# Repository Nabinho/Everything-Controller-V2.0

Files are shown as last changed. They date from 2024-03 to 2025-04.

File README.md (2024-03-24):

# Everything Controller V2.0

This project is an updated version of my Everything Controller I did a while back. This time I focused on transmission time, using the powerfull Teensy 3.2 as the main microcontroller. I also added more inputs, so I have even more functions to help the control of various projects, and not only robots.

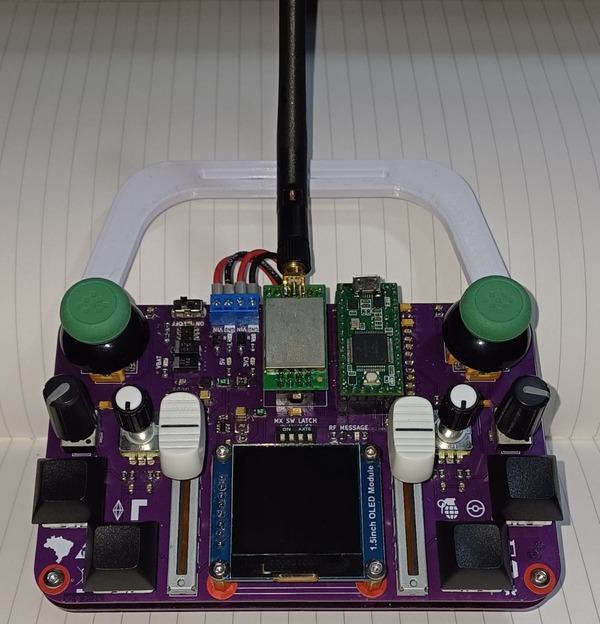
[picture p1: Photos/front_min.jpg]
Finished project


The PCB and base code of this project are available for replication. The Teensy 3.2 is discontinued, so if you don't have one, maybe this can be a great reference for your own project.

## BOM

The SMD components list can be found in the interactive BOM generated with the KiCad project. Besides the Teensy 3.2 I had for a while, the rest of the THT components I bought from Aliexpress and all of the links are listed below.

* 1x - [EByte E01](https://pt.aliexpress.com/item/1005001803228202.html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);
* 1x - [Waveshare SSD1327 128x128 OLED Display](https://pt.aliexpress.com/item/32853228170.html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);
* 2x - [10k Ohm Rotary Potentiometer](https://pt.aliexpress.com/item/1005005956593595.html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);
* 2x - [10k Ohm Slider Potentiometer](https://pt.aliexpress.com/item/1005006075347058.html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);
* 2x - [EC11 Rotary Encoder](https://pt.aliexpress.com/item/1005005882895811.html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);
* 4x - [Cherry MX Switches (any color)](https://pt.aliexpress.com/item/1005006255961111.html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);
* 2x - [PS5 Hall Effect Joystick](https://pt.aliexpress.com/item/1005006165745072.html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);

Besides the electronics components, a pair of 18650 Li-Ion batteries is necessary to power the controller.

Some screws and nuts ares also recommended to mount the soldered PCB in an acrylic or 3D printed backplate.

## Bechmark Tests

As soon as the controller was finished I ran some benchmark tests to validate the controller performance. Bellow are the tests I ran so far and the results.

| Tests | Results |
| --- |:---:|
| Battery feedback reading | The battery feedback circuit from the controller had a precision of 0.3 mV most of the time, but I had to include a "debounce" for the OLED update, due to some voltage fluctuation |
| Transmission latency | With a simple receiver just connected to the NRF24L01 transceiver and only calculating the time between messages (data sent and acknolegement) the average time was 3 ms during an 1 hour test |
| Battery duration | Using a pair of 3000 mAh 18650 Li-Ion batteries the controller stayed turned on during 21 hours (average consumption of 150 mA) |
| Transmission range | This test is still TBD, however I want to see if the optimistic expectations from EByte of a transmission range of 5 km is true |

### Conclusion/Contact

As this is a personal project, I would love to see if anyone replicate or takes inspiration from this project. So if you replicate or use this as a base for your own project, please share it with me in Instagram.

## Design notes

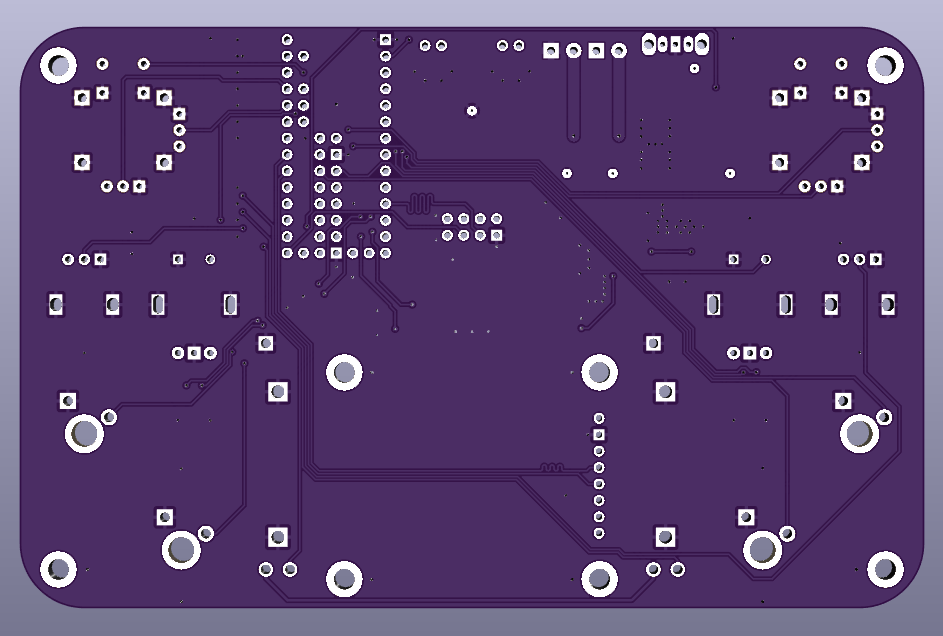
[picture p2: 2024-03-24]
Hardware/Everything_Controller_V2.0/photos/pcb_back.png

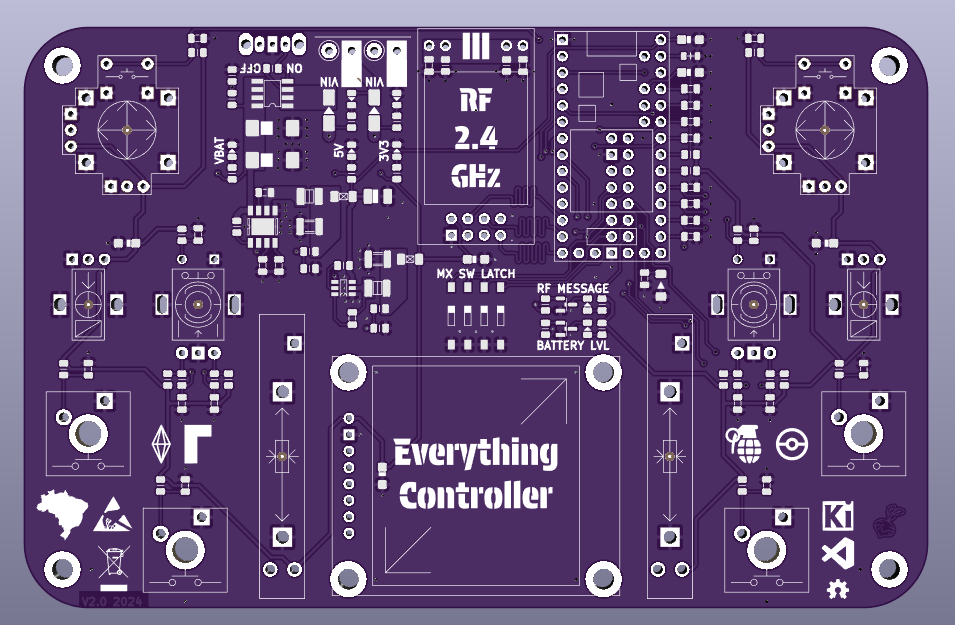
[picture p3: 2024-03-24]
Hardware/Everything_Controller_V2.0/photos/pcb_front.png

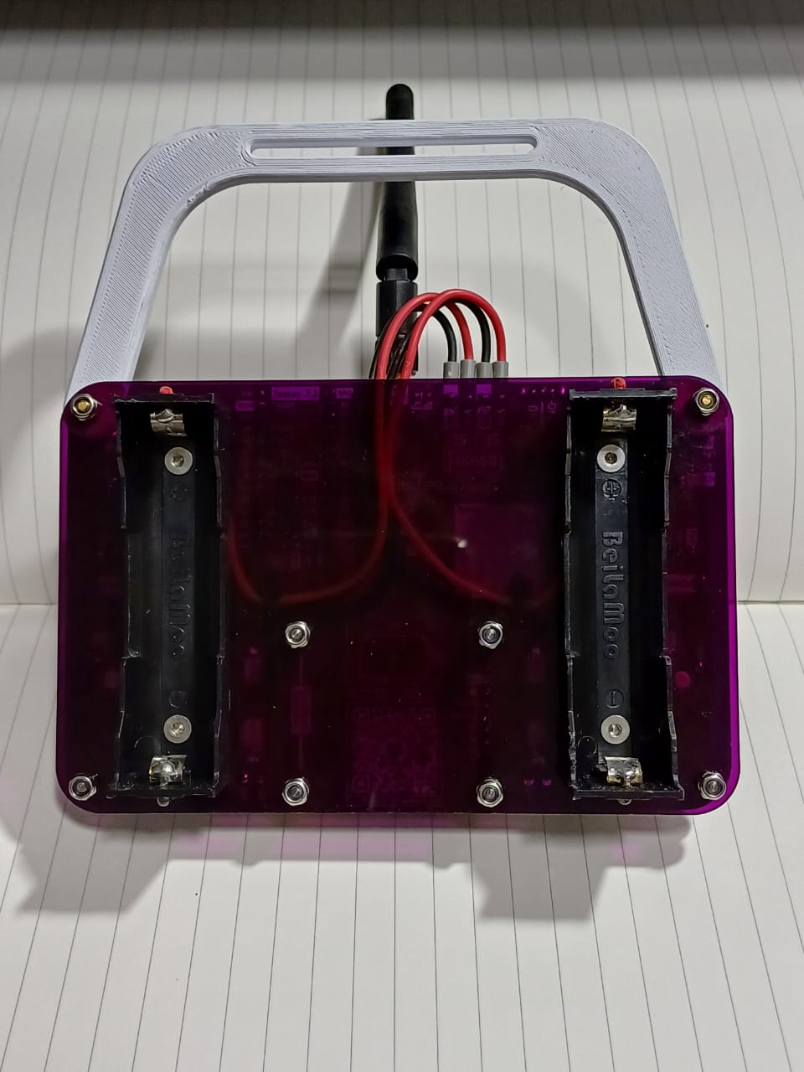
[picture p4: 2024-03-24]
Photos/back.jpg

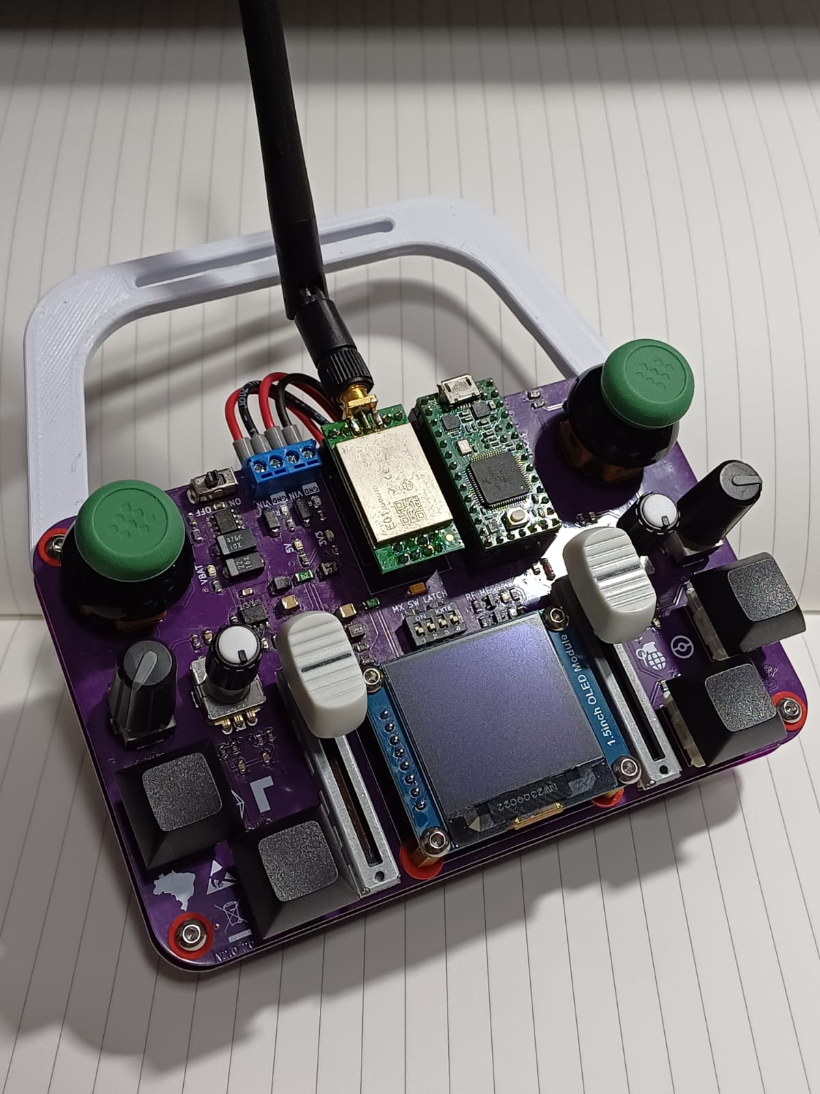
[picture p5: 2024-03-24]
Photos/isometric.jpg

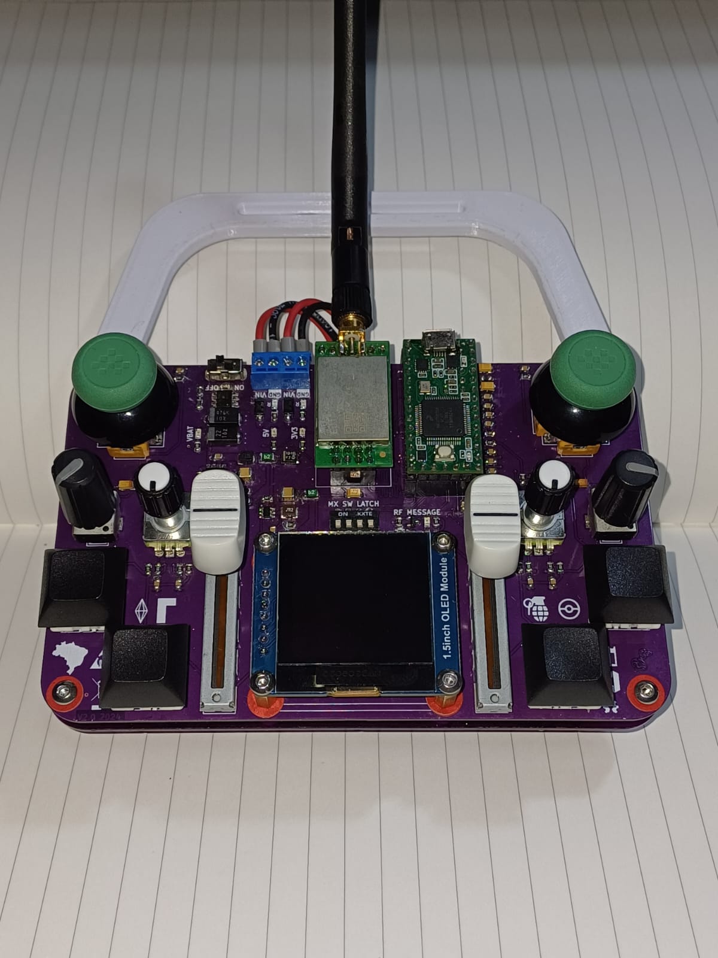
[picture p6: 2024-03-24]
Photos/front.jpg

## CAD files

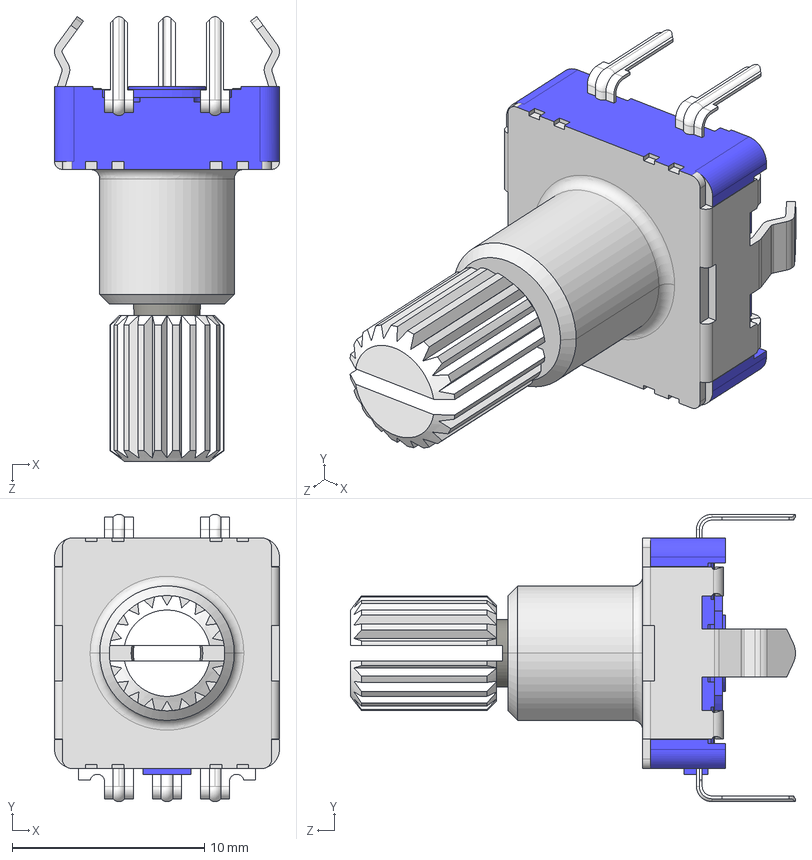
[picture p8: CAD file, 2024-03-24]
Hardware/Everything_Controller_V2.0/3d/EC11 Rotary Encoder Dode Switch-15mm .STEP
11.7 x 15.0 x 23.2 mm

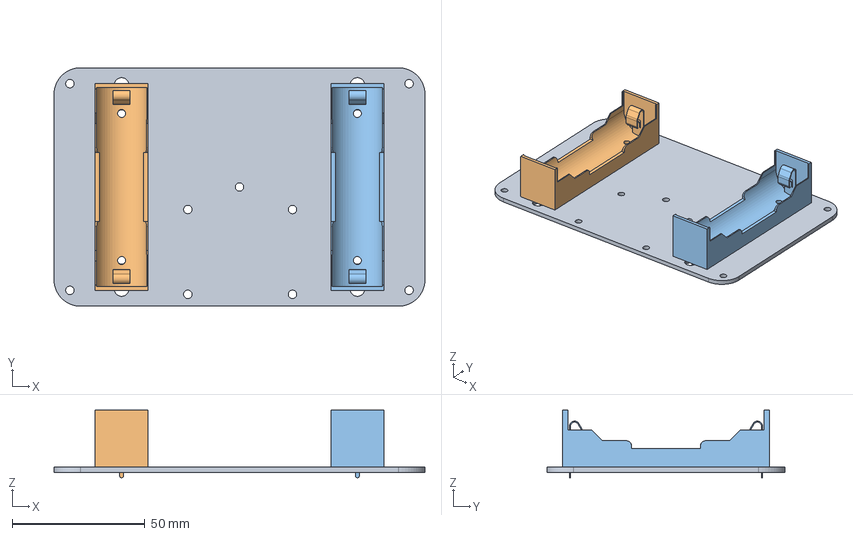
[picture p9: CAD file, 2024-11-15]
Hardware/Everything_Controller_V2.0/mechanical/Everything_Controller_Backplate.FCStd
140.0 x 90.0 x 25.5 mm
Hold_18650-1p
Hold_18650-1p001

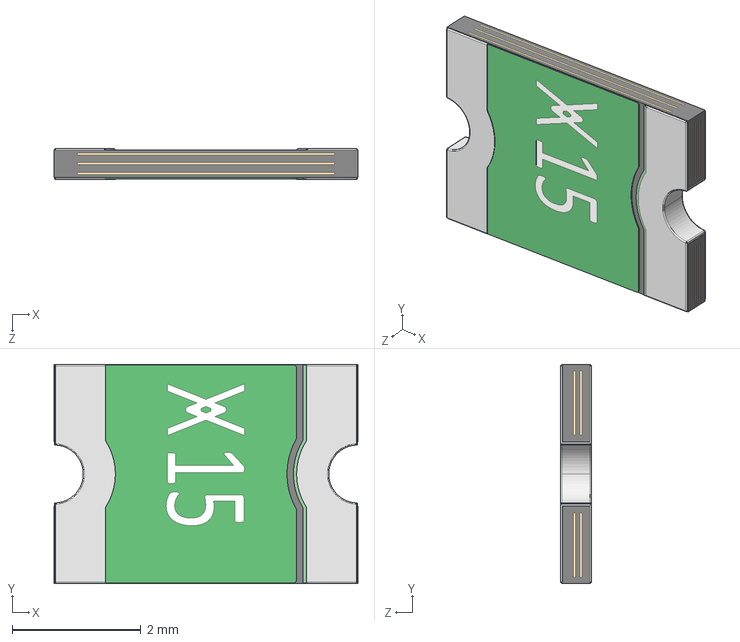
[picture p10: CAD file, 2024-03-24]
Hardware/Everything_Controller_V2.0/3d/miniSMDC150F.STEP
4.73 x 3.41 x 0.48 mm

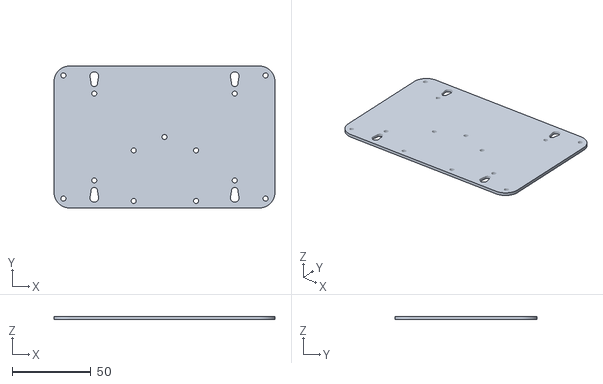
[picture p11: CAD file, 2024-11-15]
Hardware/Everything_Controller_V2.0/mechanical/Everything_Controller_Backplate-Body.stl
140.0 x 90.0 x 2.00

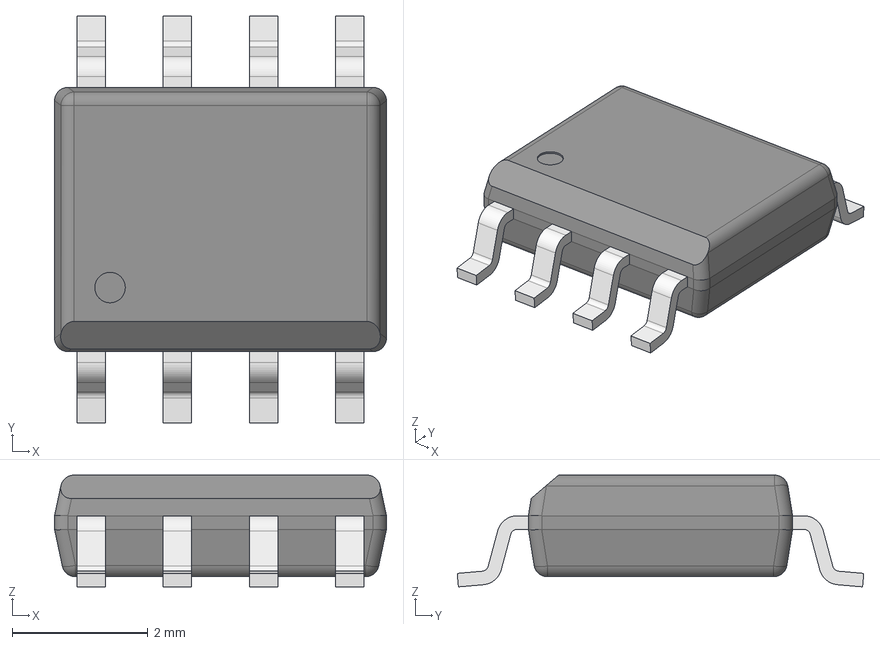
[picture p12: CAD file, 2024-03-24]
Hardware/Everything_Controller_V2.0/3d/Diodes_-_AP65552SP-13.step
4.90 x 6.00 x 1.65 mm

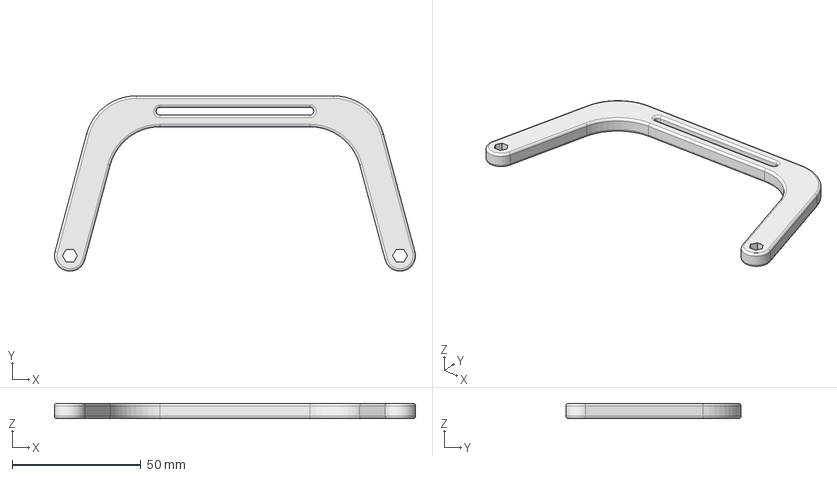
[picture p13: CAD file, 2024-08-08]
Hardware/Everything_Controller_V2.0/mechanical/Everything_Controller_Handle.FCStd
140.0 x 68.0 x 6.00 mm

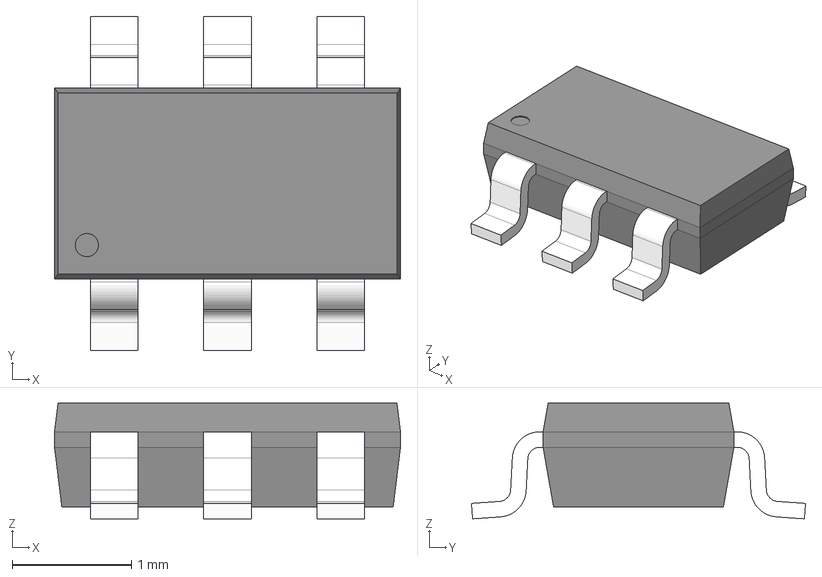
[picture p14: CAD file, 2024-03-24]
Hardware/Everything_Controller_V2.0/3d/Texas_Instruments_-_TPS564201DDCR.step
2.90 x 2.80 x 0.97 mm

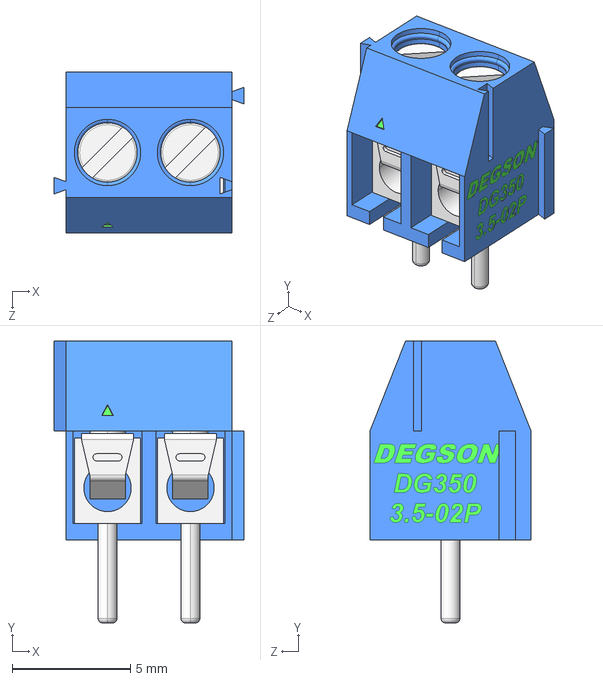
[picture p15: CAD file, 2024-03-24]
Hardware/Everything_Controller_V2.0/3d/DG350-3.5-02P-12-00AH.STEP
8.00 x 11.9 x 6.80 mm

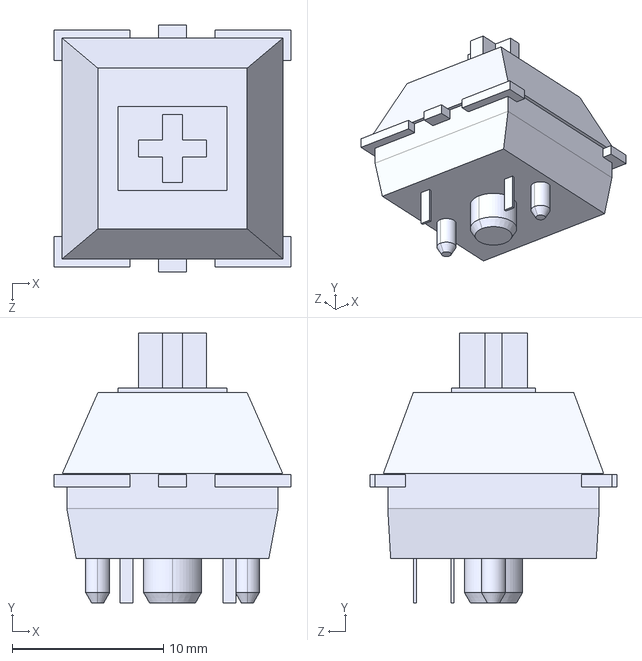
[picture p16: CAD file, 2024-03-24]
Hardware/Everything_Controller_V2.0/3d/cherry mx.STEP
15.6 x 17.9 x 16.3 mm

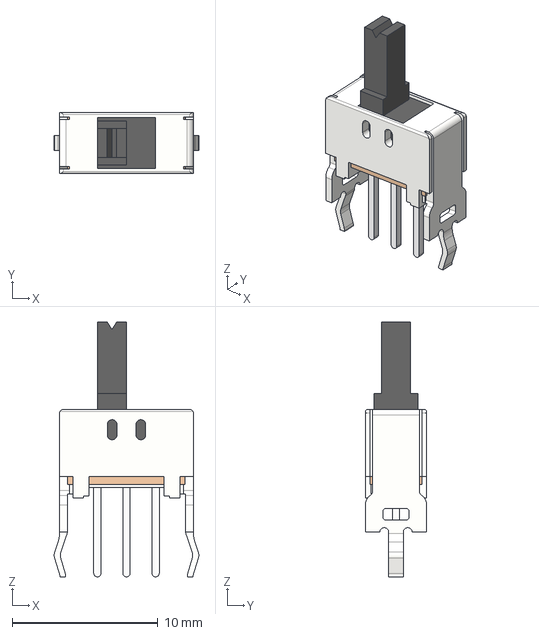
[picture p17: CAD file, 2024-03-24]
Hardware/Everything_Controller_V2.0/3d/EG1249.step
9.93 x 4.20 x 17.5 mm

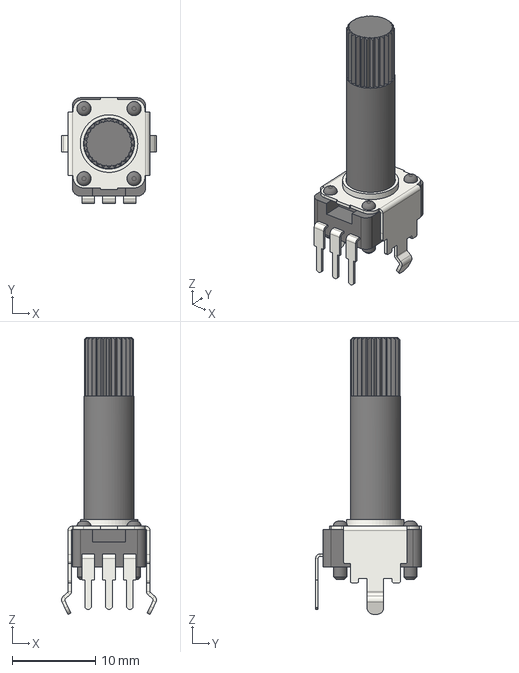
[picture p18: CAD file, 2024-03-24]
Hardware/Everything_Controller_V2.0/3d/ALPS-RK09K.step
11.4 x 12.7 x 33.2 mm

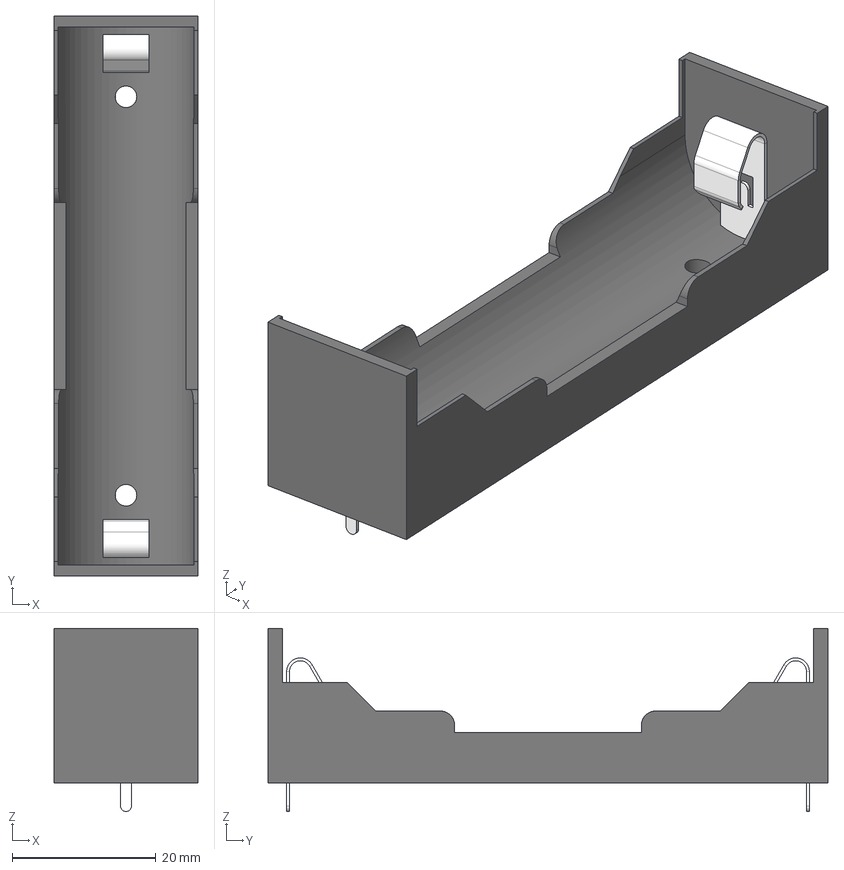
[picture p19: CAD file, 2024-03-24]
Hardware/Everything_Controller_V2.0/3d/Hold_18650-1p.stp
20.0 x 78.0 x 25.5 mm

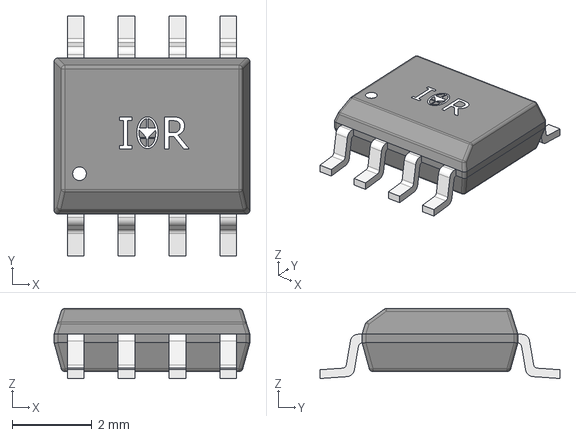
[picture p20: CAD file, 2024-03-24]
Hardware/Everything_Controller_V2.0/3d/Infineon_-_IRF7424TRPBF.step
4.90 x 6.00 x 1.75 mm

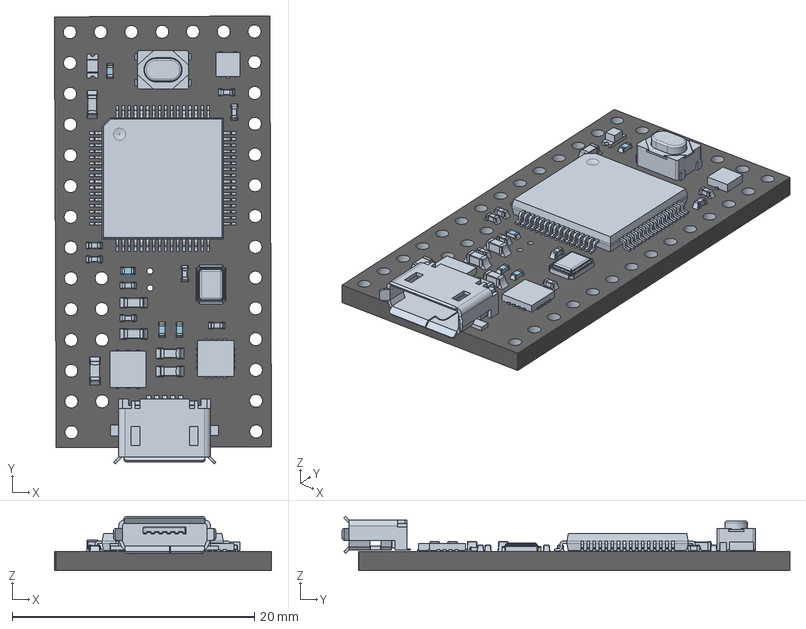
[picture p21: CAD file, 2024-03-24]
Hardware/Everything_Controller_V2.0/3d/Teensy_3_1.stp
17.9 x 37.0 x 4.49 mm
board
micro_usb_plastic (1)
micro_usb_shell (1)
lead
package (1)
lead (3) x 64
package
lead (1)
cap0402 v2 x 6
lead (2)
diode_0402 v1 x 4
cap0603_03 v3 x 5
cap0402 v2 (1) x 2
smt_led_0805 v2
resistor_0603 v3

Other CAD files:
Hardware/Everything_Controller_V2.0/3d/10K C3031 potentiometer.STEP
Hardware/Everything_Controller_V2.0/3d/SparkFun Deluxe Thumbstick with Breakout Board and Knob.step
Hardware/Everything_Controller_V2.0/mechanical/Everything_Controller_Backplate-Body.dxf

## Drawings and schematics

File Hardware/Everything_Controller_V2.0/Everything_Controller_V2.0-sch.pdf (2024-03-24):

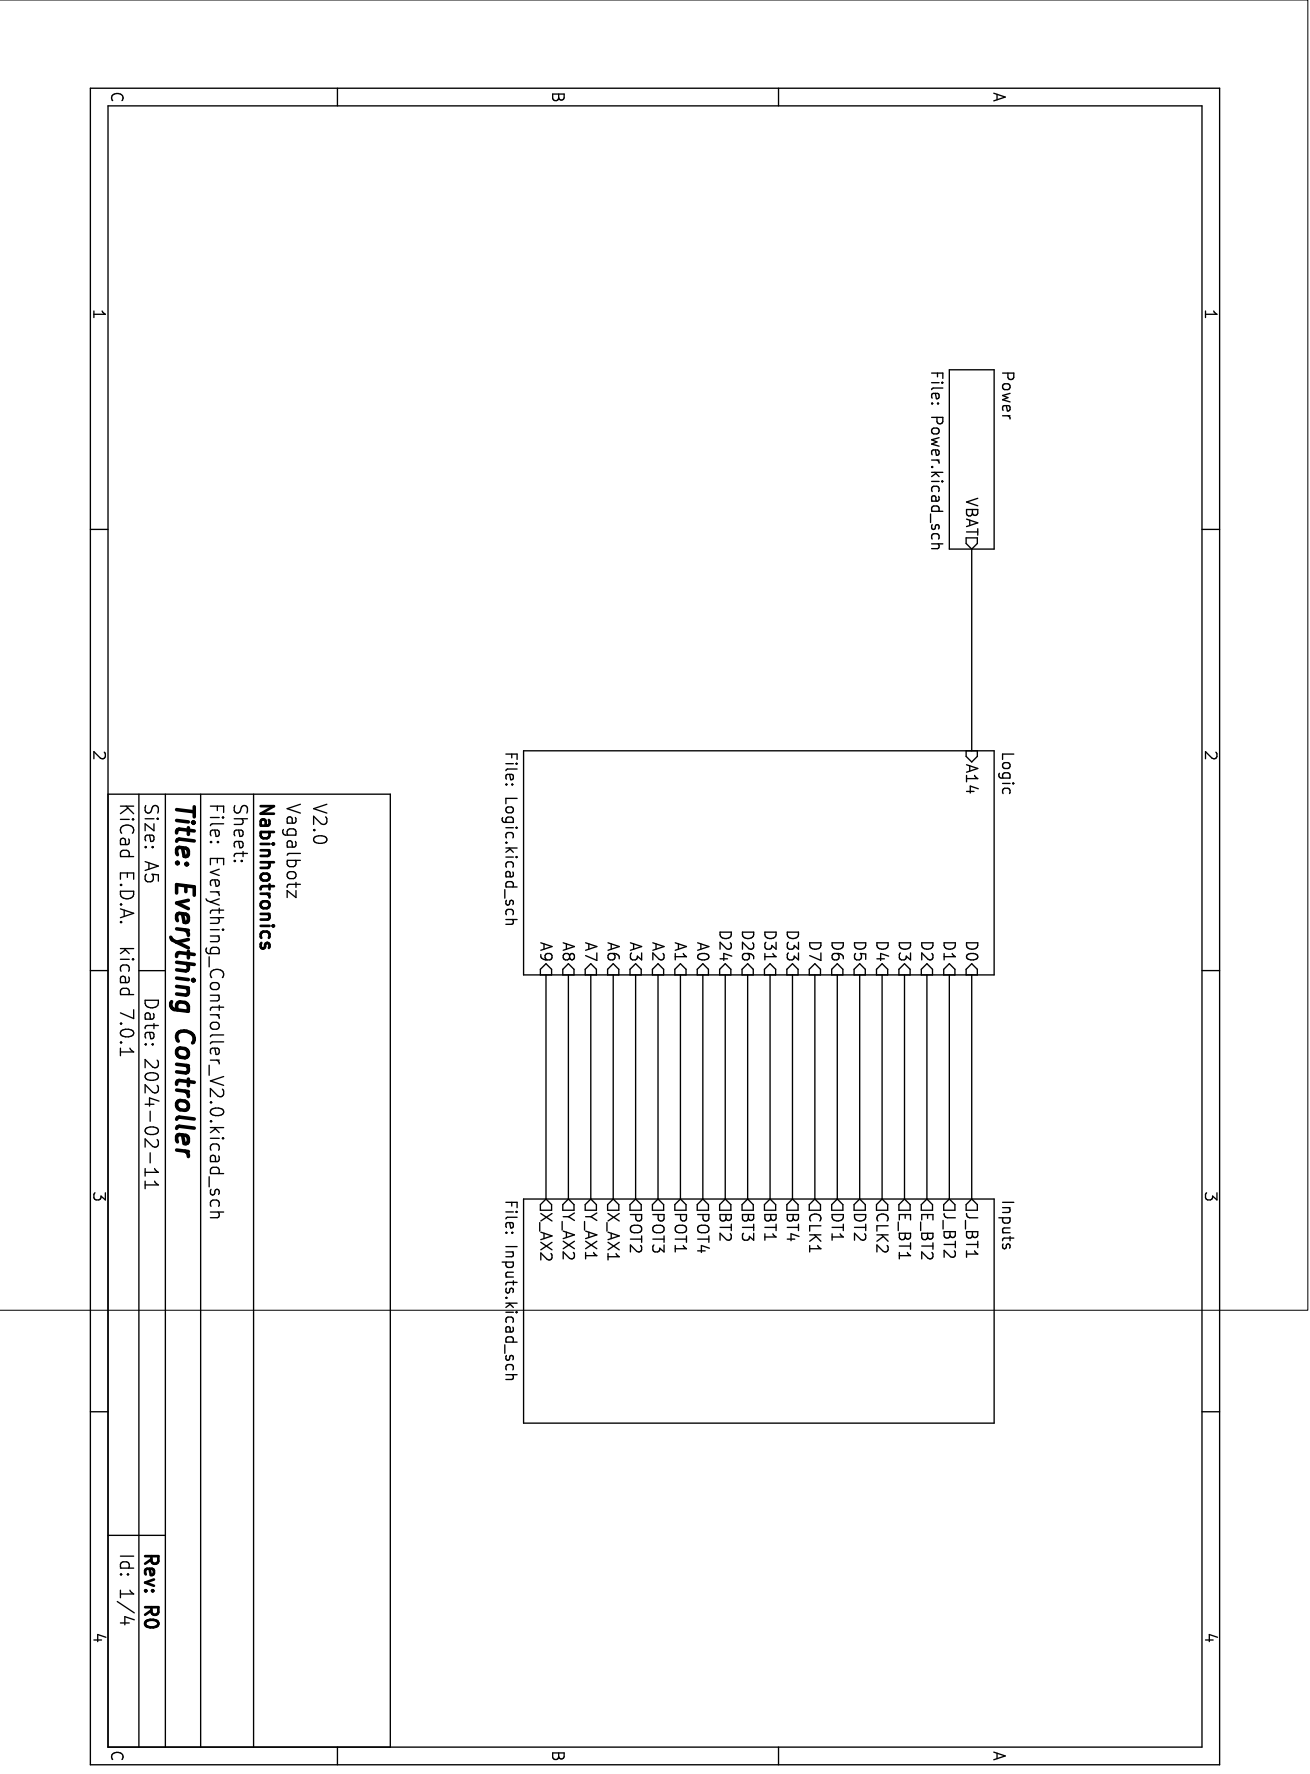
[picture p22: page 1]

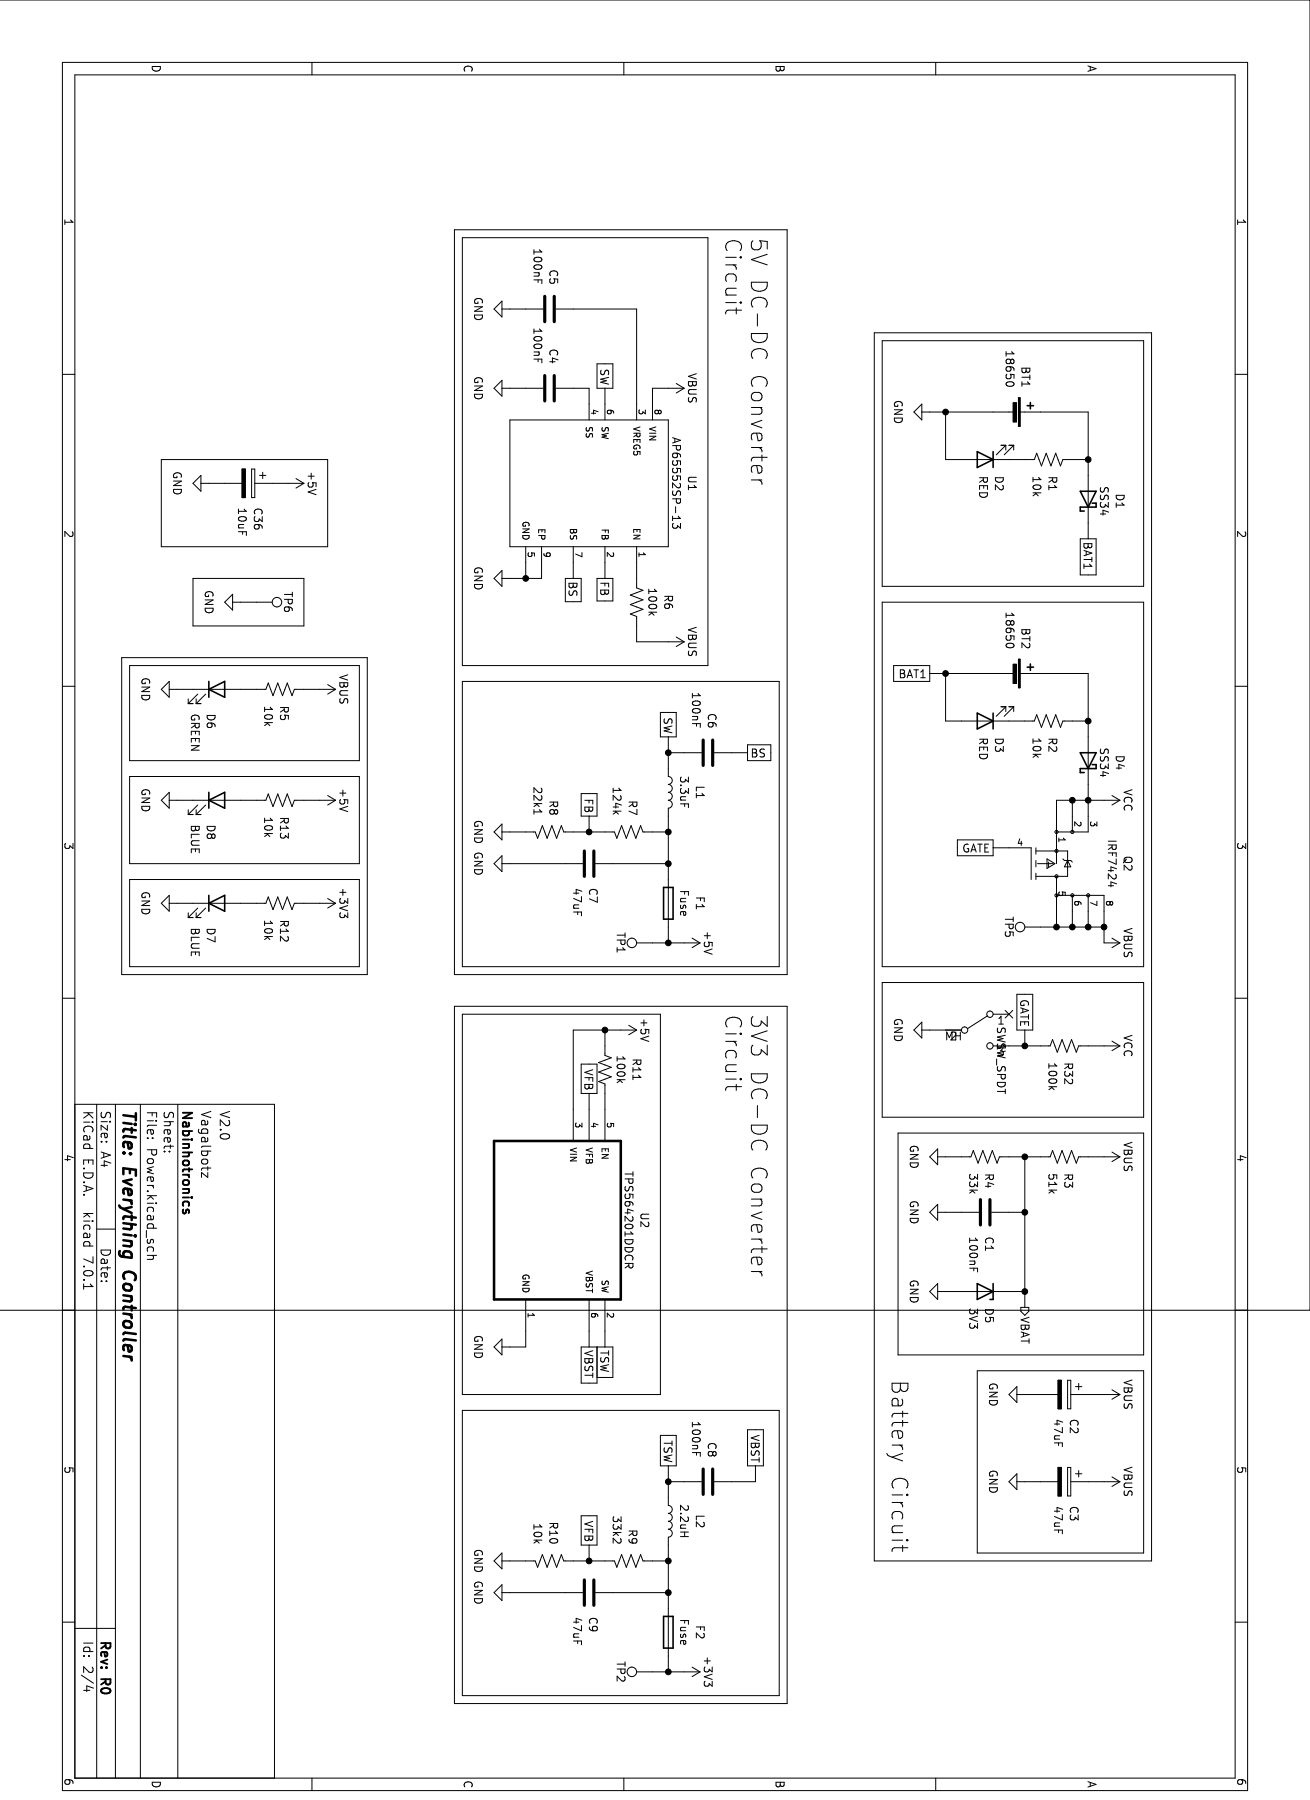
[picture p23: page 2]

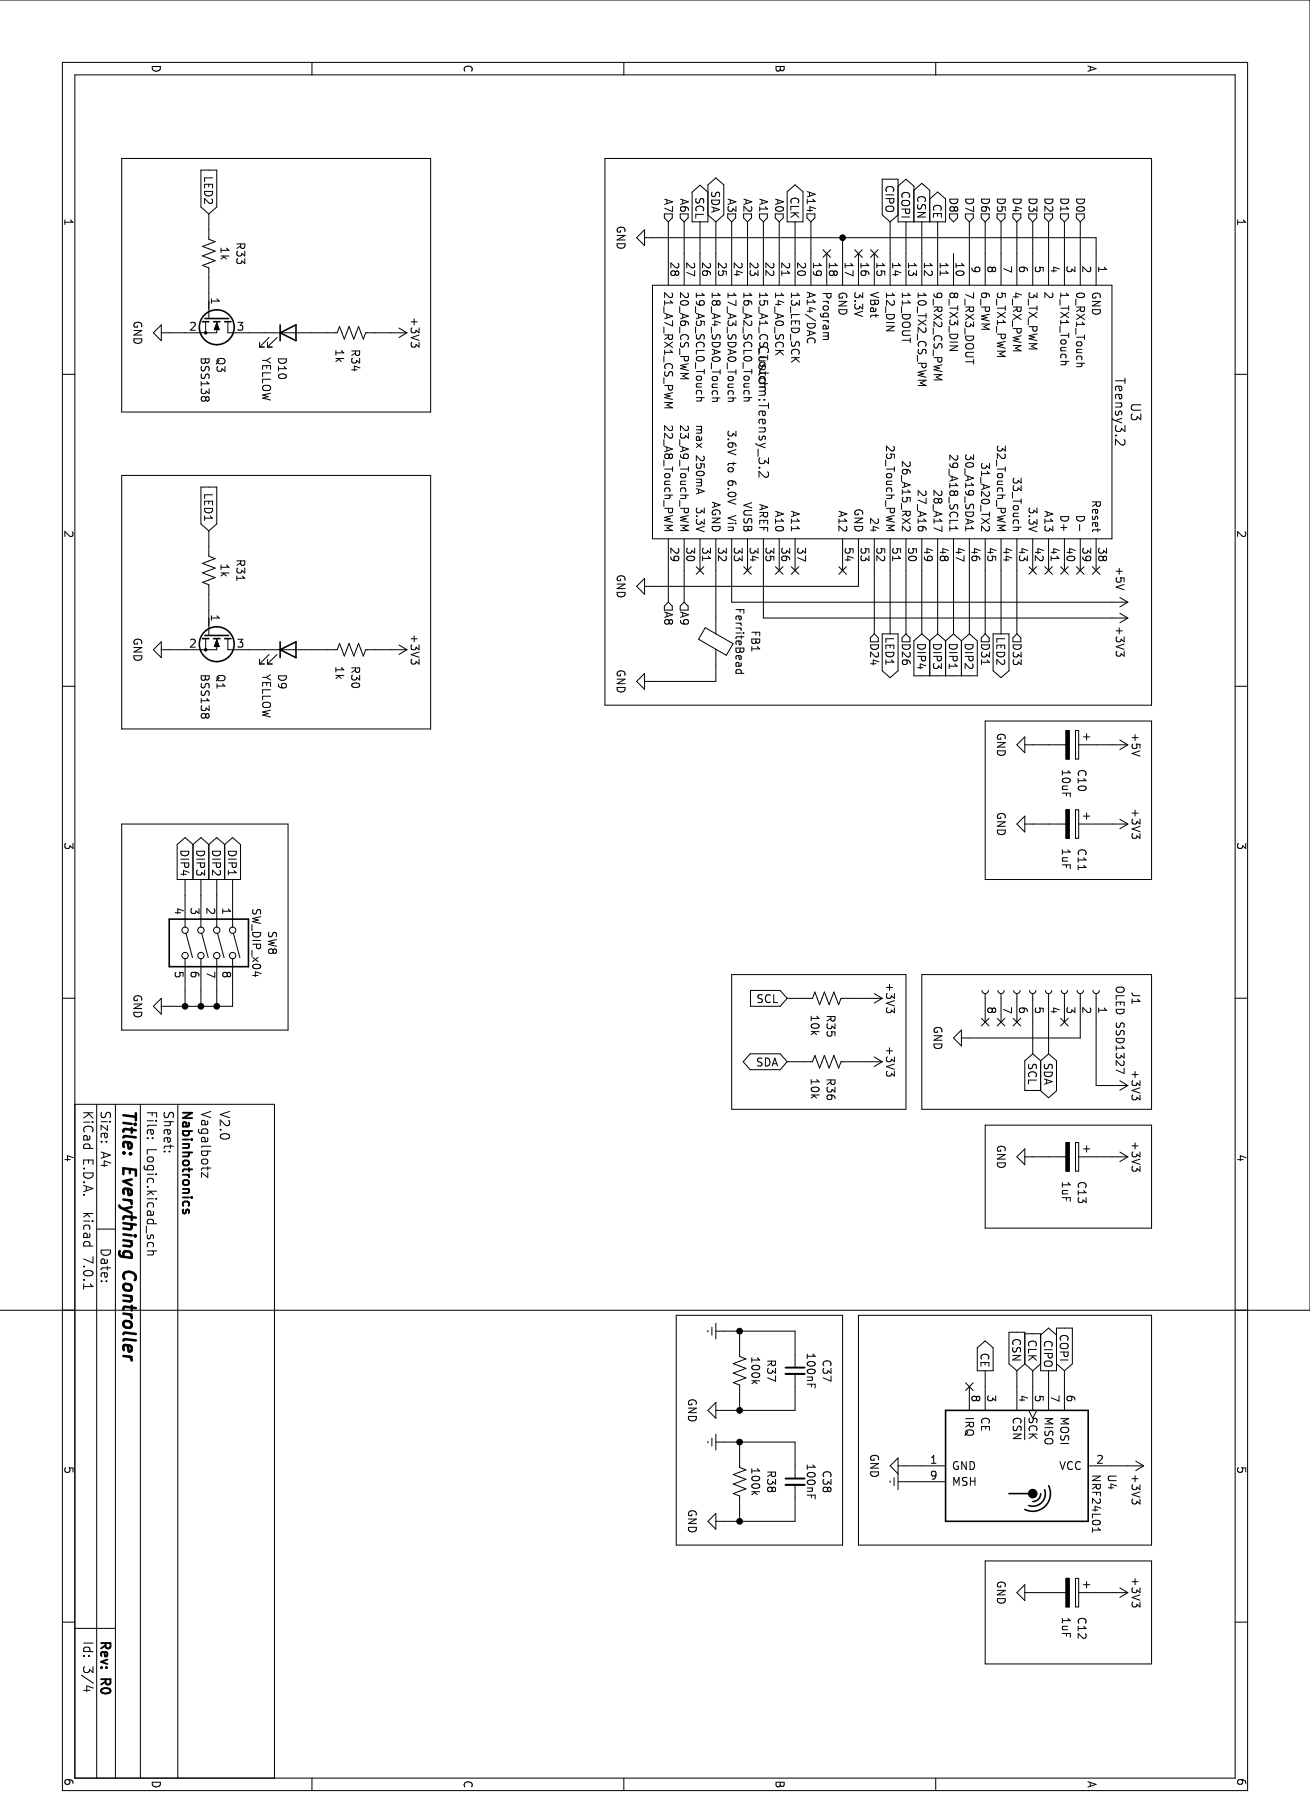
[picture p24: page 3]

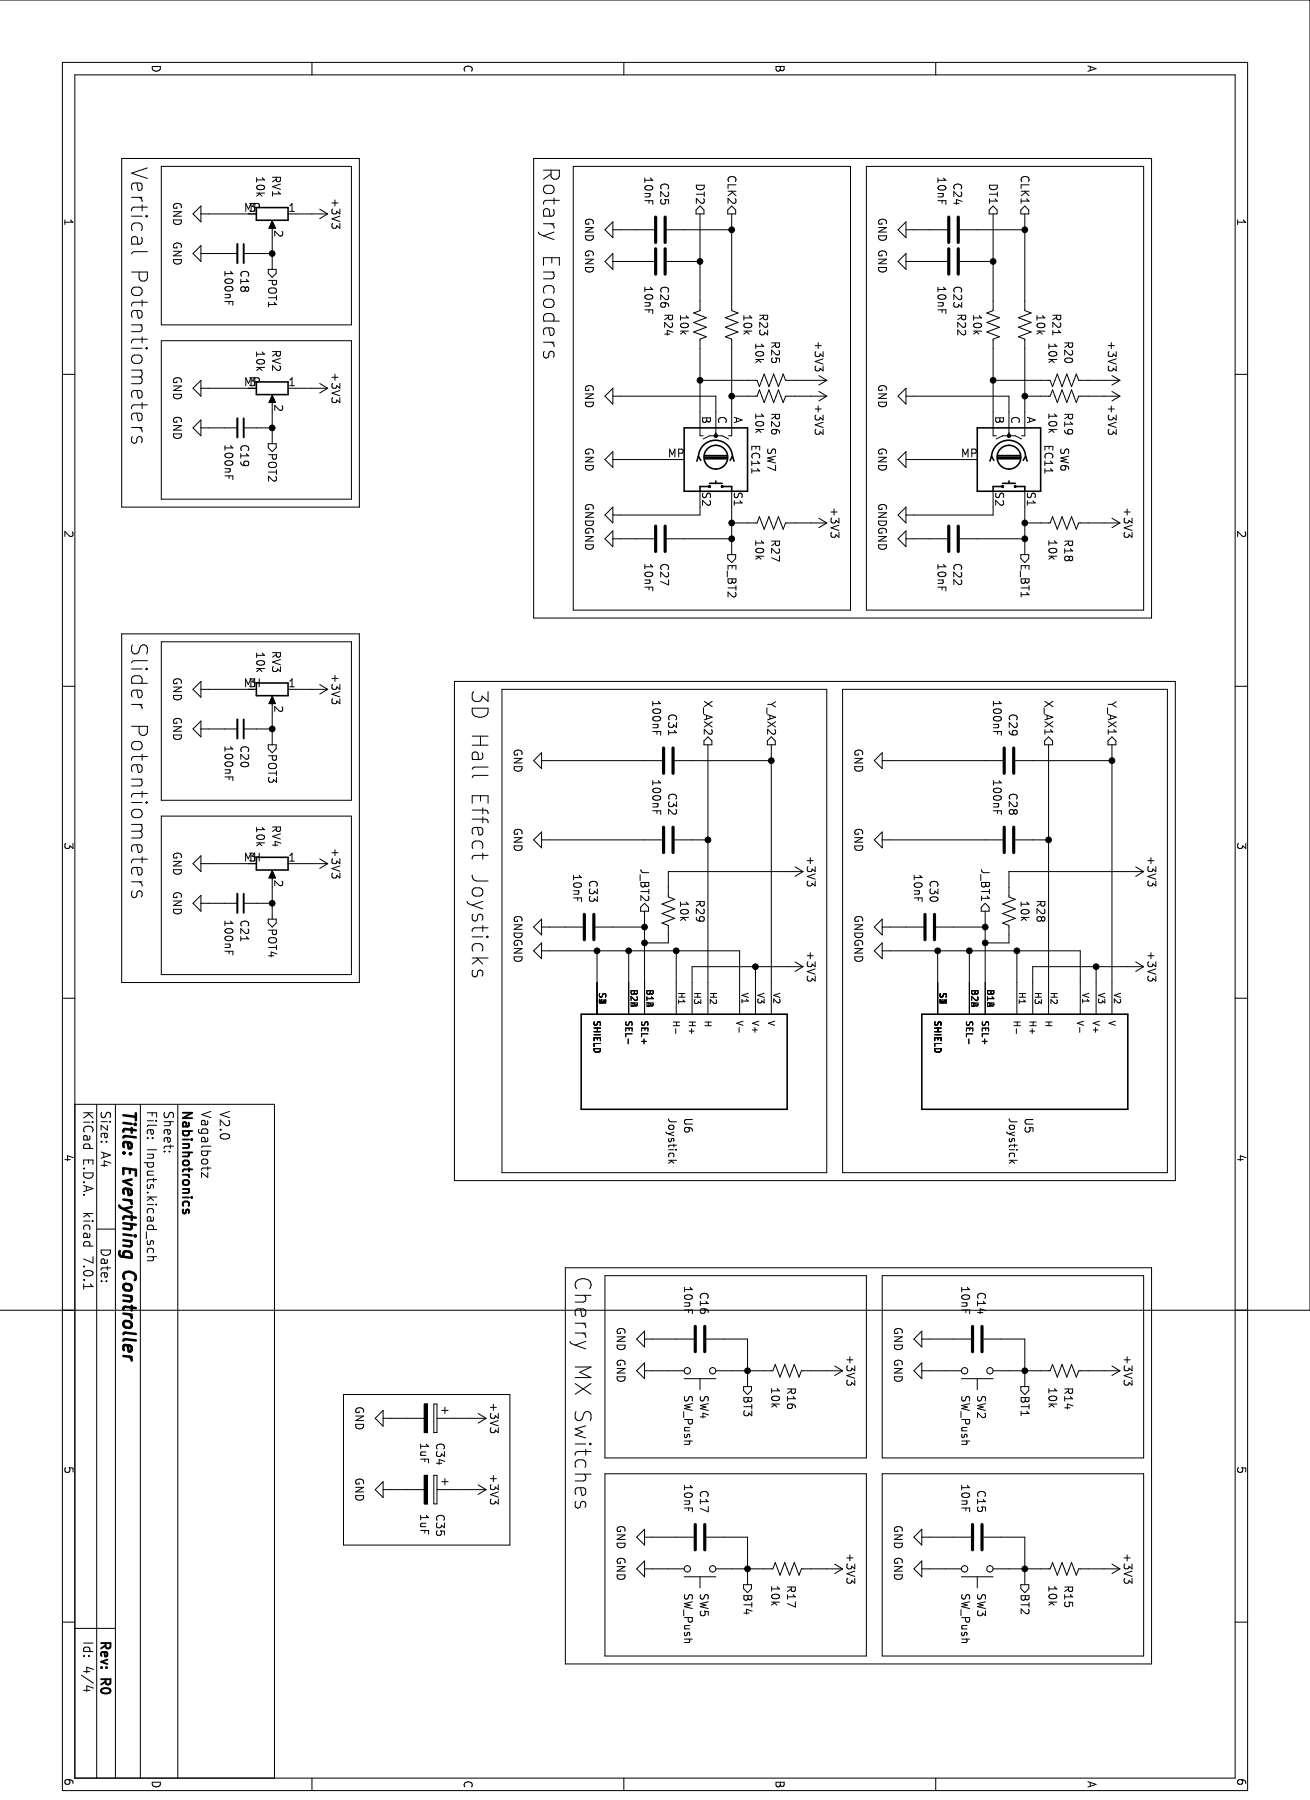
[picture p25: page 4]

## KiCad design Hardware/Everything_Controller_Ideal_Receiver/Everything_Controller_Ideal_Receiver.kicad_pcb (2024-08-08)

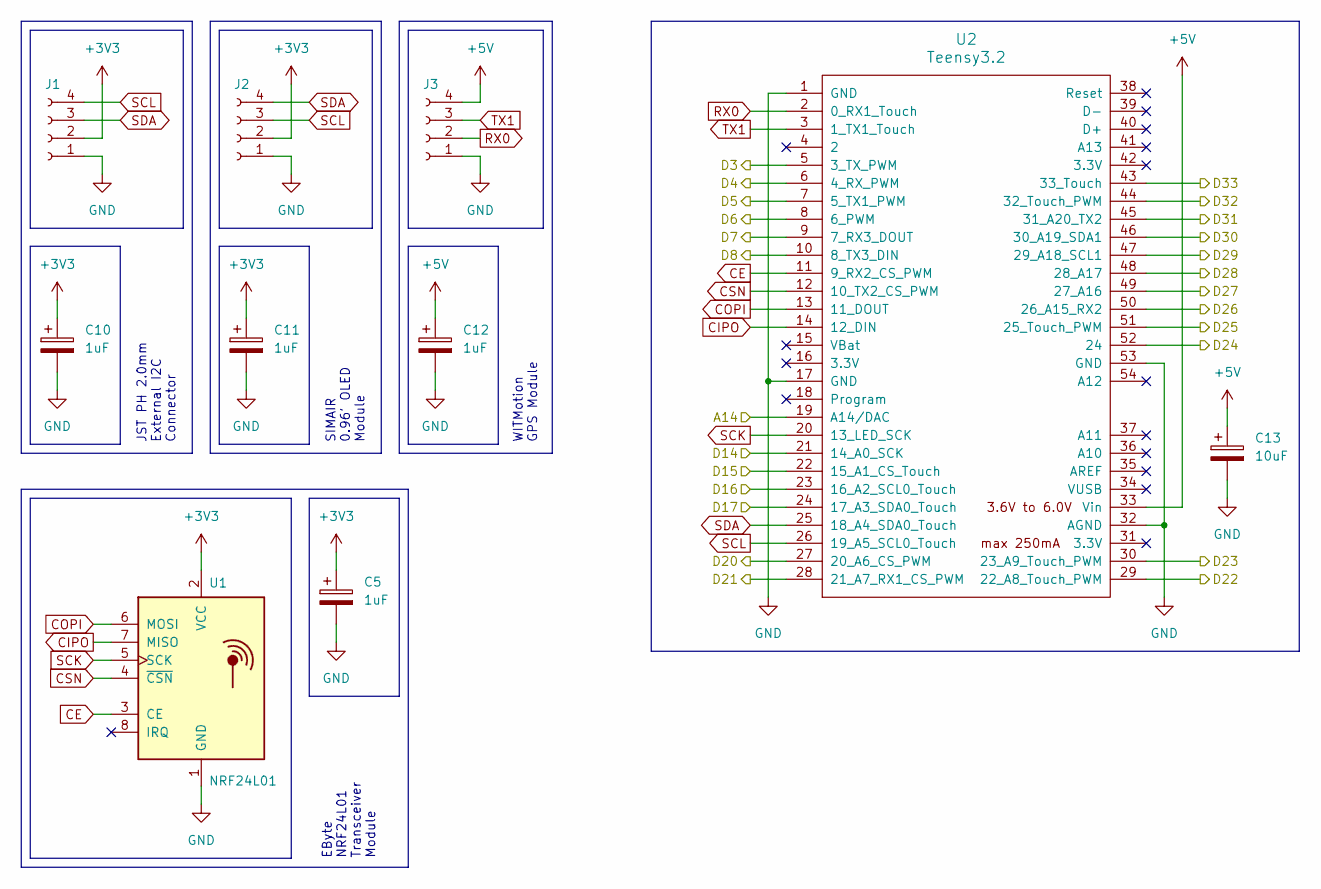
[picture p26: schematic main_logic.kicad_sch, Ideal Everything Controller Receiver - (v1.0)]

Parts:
C5, C10, C11, C12: 1uF; CP_EIA-3216-18_Kemet-A
C13: 10uF; CP_EIA-3528-21_Kemet-B
J1: Conn_01x04_Socket; JST_PH_S4B-PH-K_1x04_P2.00mm_Horizontal
J2: Conn_01x04_Socket; SIMAIR_OLED
J3: Conn_01x04_Socket; WitMotion_NMEA0183
U1: NRF24L01; EByte_NRF24L01_Breakout
U2: Teensy3.2; Teensy_3.2

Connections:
+3V3: C5.1, C10.1, C11.1, J1.2, J2.2, U1.2 (VCC); also elsewhere on the board
+5V: C12.1, C13.1, J3.4, U2.33 (Vin); also elsewhere on the board
/Inputs and Outputs/BOTAO1: U2.21 (14_A0_SCK); also elsewhere on the board
/Inputs and Outputs/BOTAO2: U2.22 (15_A1_CS_Touch); also elsewhere on the board
/Inputs and Outputs/BOTAO3: U2.23 (16_A2_SCL0_Touch); also elsewhere on the board
/Inputs and Outputs/BOTAO4: U2.24 (17_A3_SDA0_Touch); also elsewhere on the board
/Inputs and Outputs/DOUT1: U2.47 (29_A18_SCL1); also elsewhere on the board
/Inputs and Outputs/DOUT2: U2.46 (30_A19_SDA1); also elsewhere on the board
/Inputs and Outputs/DOUT3: U2.45 (31_A20_TX2); also elsewhere on the board
/Inputs and Outputs/DOUT4: U2.48 (28_A17); also elsewhere on the board
/Inputs and Outputs/DOUT5: U2.49 (27_A16); also elsewhere on the board
/Inputs and Outputs/DOUT6: U2.50 (26_A15_RX2); also elsewhere on the board
/Inputs and Outputs/DOUT7: U2.51 (25_Touch_PWM); also elsewhere on the board
/Inputs and Outputs/DOUT8: U2.52 (24); also elsewhere on the board
/Inputs and Outputs/LED1: U2.44 (32_Touch_PWM); also elsewhere on the board
/Inputs and Outputs/LED2: U2.43 (33_Touch); also elsewhere on the board
/Inputs and Outputs/PPM1: U2.29 (22_A8_Touch_PWM); also elsewhere on the board
/Inputs and Outputs/PPM2: U2.30 (23_A9_Touch_PWM); also elsewhere on the board
/Inputs and Outputs/PWM1: U2.10 (8_TX3_DIN); also elsewhere on the board
/Inputs and Outputs/PWM2: U2.9 (7_RX3_DOUT); also elsewhere on the board
/Inputs and Outputs/PWM3: U2.8 (6_PWM); also elsewhere on the board
/Inputs and Outputs/PWM4: U2.7 (5_TX1_PWM); also elsewhere on the board
/Inputs and Outputs/PWM5: U2.6 (4_RX_PWM); also elsewhere on the board
/Inputs and Outputs/PWM6: U2.5 (3_TX_PWM); also elsewhere on the board
/Inputs and Outputs/PWM7: U2.27 (20_A6_CS_PWM); also elsewhere on the board
/Inputs and Outputs/PWM8: U2.28 (21_A7_RX1_CS_PWM); also elsewhere on the board
/Main Logic/A14: U2.19 (A14/DAC); also elsewhere on the board
CE: U1.3 (CE), U2.11 (9_RX2_CS_PWM)
CIPO: U1.7 (MISO), U2.14 (12_DIN)
COPI: U1.6 (MOSI), U2.13 (11_DOUT)
CSN: U1.4 (~CSN), U2.12 (10_TX2_CS_PWM)
GND: C5.2, C10.2, C11.2, C12.2, C13.2, J1.1, J2.1, J3.1, U1.1 (GND), U2.1 (GND), U2.17 (GND), U2.32 (AGND), U2.53 (GND); also elsewhere on the board
RX0: J3.2, U2.2 (0_RX1_Touch)
SCK: U1.5 (SCK), U2.20 (13_LED_SCK)
SCL: J1.4, J2.3, U2.26 (19_A5_SCL0_Touch)
SDA: J1.3, J2.4, U2.25 (18_A4_SDA0_Touch)
TX1: J3.3, U2.3 (1_TX1_Touch)

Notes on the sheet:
SIMAIR 0.96' OLED Module
WITMotion GPS Module
JST PH 2.0mm External I2C Connector
EByte NRF24L01 Transceiver Module

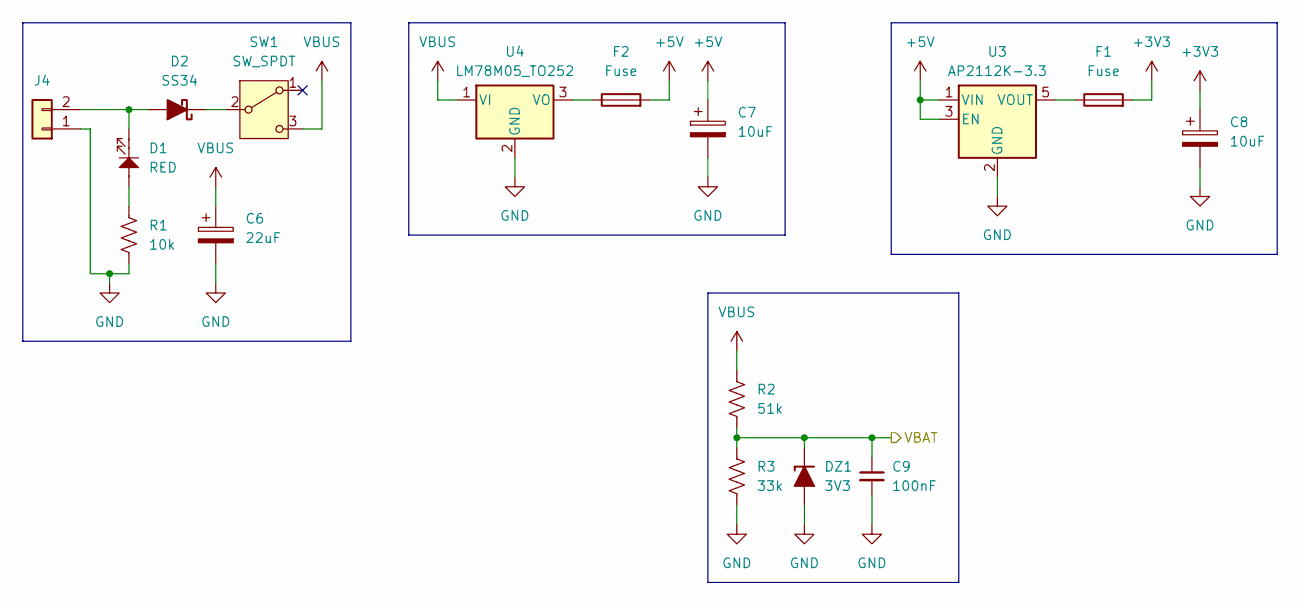
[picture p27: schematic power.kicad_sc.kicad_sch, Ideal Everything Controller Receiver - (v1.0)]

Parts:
C6: 22uF; CP_EIA-7343-31_Kemet-D
C7, C8: 10uF; CP_EIA-3528-21_Kemet-B
C9: 100nF; C_0805_2012Metric
D1: RED; LED_0805_2012Metric
D2: SS34; D_SMA
DZ1: 3V3; D_MiniMELF
F1: Fuse; Fuse_0805_2012Metric
F2: Fuse; Fuse_1812_4532Metric
J4: Conn_01x02; TerminalBlock_4Ucon_1x02_P3.50mm_Horizontal
R1: 10k; R_0805_2012Metric
R2: 51k; R_0805_2012Metric
R3: 33k; R_0805_2012Metric
SW1: SW_SPDT; SW_Slide_SPDT_Straight_CK_OS102011MS2Q
U3: AP2112K-3.3; SOT-23-5
U4: LM78M05_TO252; TO-252-2

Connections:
+3V3: C8.1, F1.2; also elsewhere on the board
+5V: C7.1, F2.2, U3.1 (VIN), U3.3 (EN); also elsewhere on the board
/Main Logic/A14: C9.1, DZ1.1 (K), R2.2, R3.1; also elsewhere on the board
GND: C6.2, C7.2, C8.2, C9.2, DZ1.2 (A), J4.1, R1.2, R3.2, U3.2 (GND), U4.2 (GND); also elsewhere on the board
unnamed: D1.2, R1.1
unnamed: D1.1, D2.2 (A), J4.2
unnamed: D2.1 (K), SW1.2 (B)
unnamed: F1.1, U3.5 (VOUT)
unnamed: F2.1, U4.3 (VO)
VBUS: C6.1, R2.1, SW1.3 (C), U4.1 (VI)

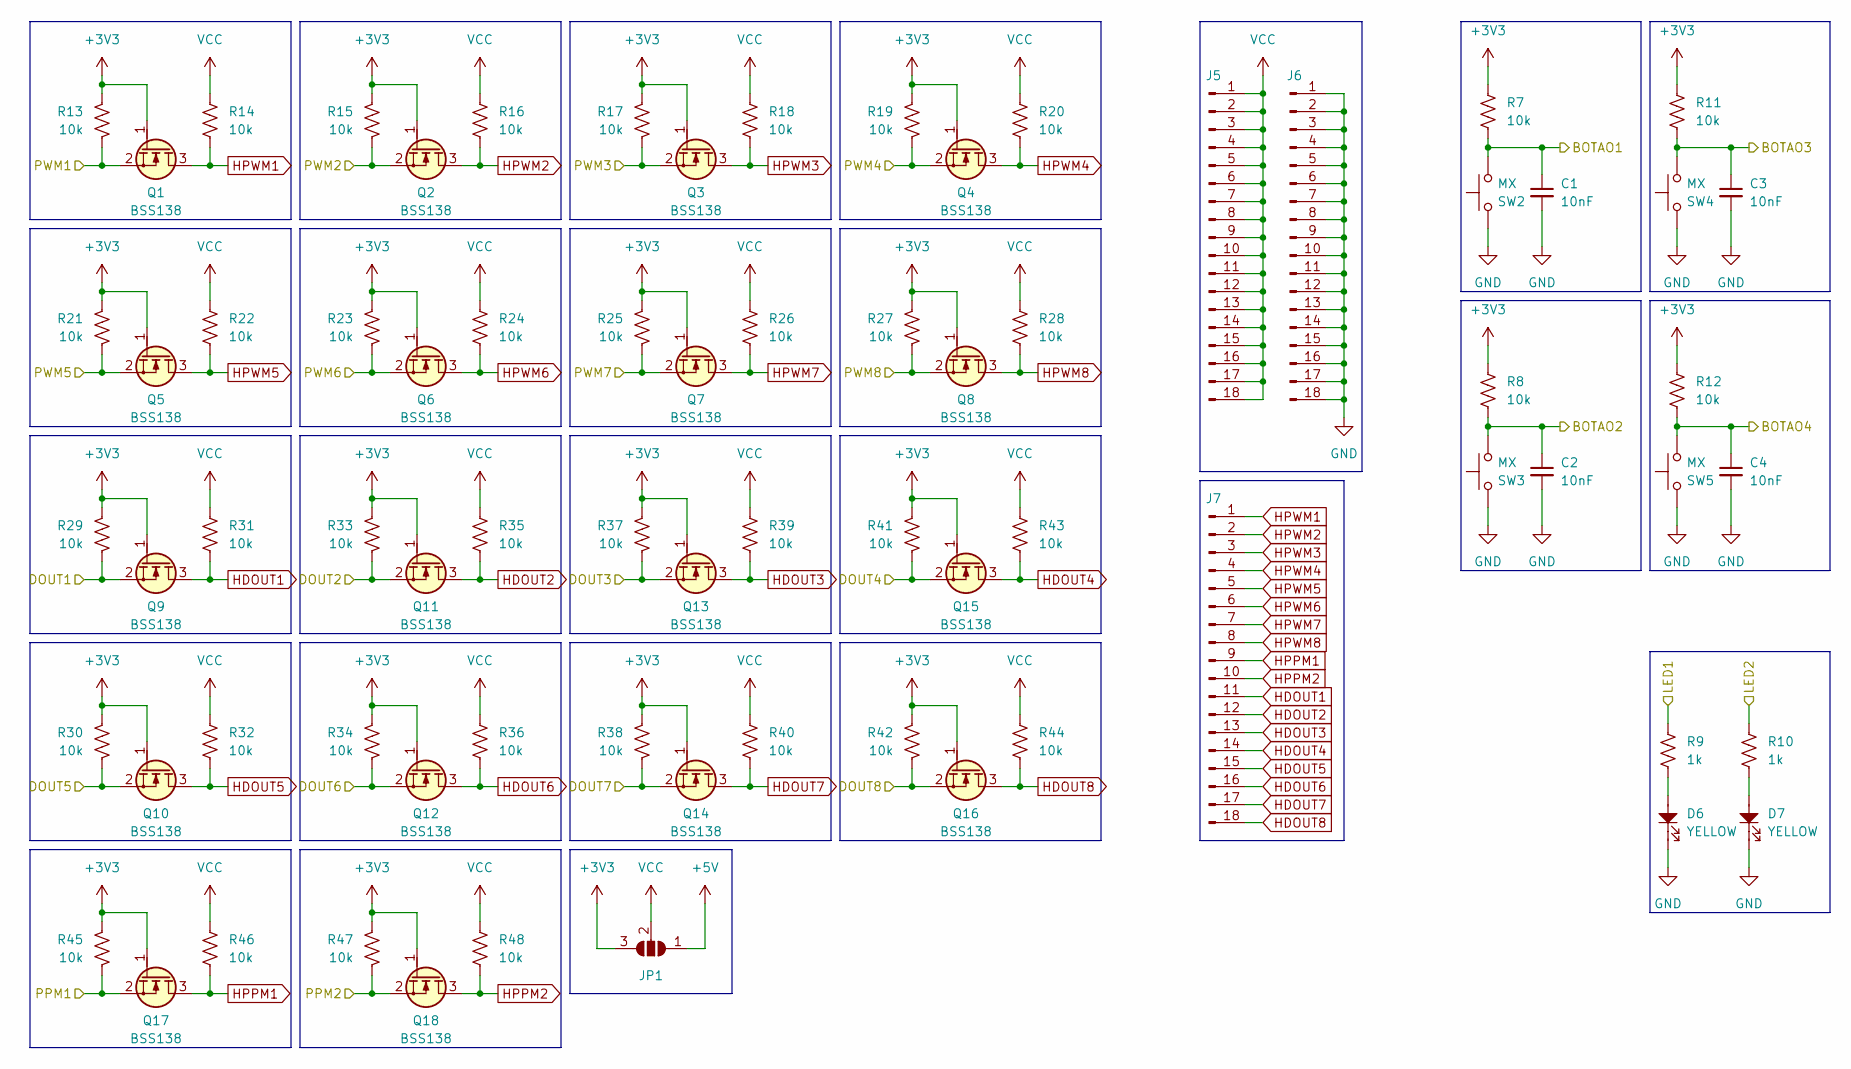
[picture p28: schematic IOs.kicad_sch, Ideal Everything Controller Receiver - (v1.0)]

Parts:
C1, C2, C3, C4: 10nF; C_0805_2012Metric
D6, D7: YELLOW; LED_0805_2012Metric
J5, J6, J7: Conn_01x18_Pin; PinHeader_1x18_P2.54mm_Vertical
JP1: SolderJumper_3_Open; SolderJumper-3_P1.3mm_Open_RoundedPad1.0x1.5mm
Q1, Q2, Q3, Q4, Q5, Q6, Q7, Q8, Q9, Q10, Q11, Q12, Q13, Q14, Q15, Q16, Q17, Q18: BSS138; SOT-23
R7, R8, R11, R12, R13, R14, R15, R16, R17, R18, R19, R20, R21, R22, R23, R24, R25, R26, R27, R28, R29, R30, R31, R32, R33, R34, R35, R36, R37, R38, R39, R40, R41, R42, R43, R44, R45, R46, R47, R48: 10k; R_0805_2012Metric
R9, R10: 1k; R_0805_2012Metric
SW2, SW3, SW4, SW5: MX; SW_Cherry_MX_PCB_1.00u

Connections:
+3V3: JP1.3 (B), Q1.1 (G), Q2.1 (G), Q3.1 (G), Q4.1 (G), Q5.1 (G), Q6.1 (G), Q7.1 (G), Q8.1 (G), Q9.1 (G), Q10.1 (G), Q11.1 (G), Q12.1 (G), Q13.1 (G), Q14.1 (G), Q15.1 (G), Q16.1 (G), Q17.1 (G), Q18.1 (G), R7.1, R8.1, R11.1, R12.1, R13.1, R15.1, R17.1, R19.1, R21.1, R23.1, R25.1, R27.1, R29.1, R30.1, R33.1, R34.1, R37.1, R38.1, R41.1, R42.1, R45.1, R47.1; also elsewhere on the board
+5V: JP1.1 (A); also elsewhere on the board
/Inputs and Outputs/BOTAO1: C1.1, R7.2, SW2.1; also elsewhere on the board
/Inputs and Outputs/BOTAO2: C2.1, R8.2, SW3.1; also elsewhere on the board
/Inputs and Outputs/BOTAO3: C3.1, R11.2, SW4.1; also elsewhere on the board
/Inputs and Outputs/BOTAO4: C4.1, R12.2, SW5.1; also elsewhere on the board
/Inputs and Outputs/DOUT1: Q9.2 (S), R29.2; also elsewhere on the board
/Inputs and Outputs/DOUT2: Q11.2 (S), R33.2; also elsewhere on the board
/Inputs and Outputs/DOUT3: Q13.2 (S), R37.2; also elsewhere on the board
/Inputs and Outputs/DOUT4: Q15.2 (S), R41.2; also elsewhere on the board
/Inputs and Outputs/DOUT5: Q10.2 (S), R30.2; also elsewhere on the board
/Inputs and Outputs/DOUT6: Q12.2 (S), R34.2; also elsewhere on the board
/Inputs and Outputs/DOUT7: Q14.2 (S), R38.2; also elsewhere on the board
/Inputs and Outputs/DOUT8: Q16.2 (S), R42.2; also elsewhere on the board
/Inputs and Outputs/LED1: R9.1; also elsewhere on the board
/Inputs and Outputs/LED2: R10.1; also elsewhere on the board
/Inputs and Outputs/PPM1: Q17.2 (S), R45.2; also elsewhere on the board
/Inputs and Outputs/PPM2: Q18.2 (S), R47.2; also elsewhere on the board
/Inputs and Outputs/PWM1: Q1.2 (S), R13.2; also elsewhere on the board
/Inputs and Outputs/PWM2: Q2.2 (S), R15.2; also elsewhere on the board
/Inputs and Outputs/PWM3: Q3.2 (S), R17.2; also elsewhere on the board
/Inputs and Outputs/PWM4: Q4.2 (S), R19.2; also elsewhere on the board
/Inputs and Outputs/PWM5: Q5.2 (S), R21.2; also elsewhere on the board
/Inputs and Outputs/PWM6: Q6.2 (S), R23.2; also elsewhere on the board
/Inputs and Outputs/PWM7: Q7.2 (S), R25.2; also elsewhere on the board
/Inputs and Outputs/PWM8: Q8.2 (S), R27.2; also elsewhere on the board
GND: C1.2, C2.2, C3.2, C4.2, D6.1, D7.1, J6.1, J6.2, J6.3, J6.4, J6.5, J6.6, J6.7, J6.8, J6.9, J6.10, J6.11, J6.12, J6.13, J6.14, J6.15, J6.16, J6.17, J6.18, SW2.2, SW3.2, SW4.2, SW5.2; also elsewhere on the board
HDOUT1: J7.11, Q9.3 (D), R31.2
HDOUT2: J7.12, Q11.3 (D), R35.2
HDOUT3: J7.13, Q13.3 (D), R39.2
HDOUT4: J7.14, Q15.3 (D), R43.2
HDOUT5: J7.15, Q10.3 (D), R32.2
HDOUT6: J7.16, Q12.3 (D), R36.2
HDOUT7: J7.17, Q14.3 (D), R40.2
HDOUT8: J7.18, Q16.3 (D), R44.2
HPPM1: J7.9, Q17.3 (D), R46.2
HPPM2: J7.10, Q18.3 (D), R48.2
HPWM1: J7.1, Q1.3 (D), R14.2
HPWM2: J7.2, Q2.3 (D), R16.2
HPWM3: J7.3, Q3.3 (D), R18.2
HPWM4: J7.4, Q4.3 (D), R20.2
HPWM5: J7.5, Q5.3 (D), R22.2
HPWM6: J7.6, Q6.3 (D), R24.2
HPWM7: J7.7, Q7.3 (D), R26.2
HPWM8: J7.8, Q8.3 (D), R28.2
unnamed: D6.2, R9.2
unnamed: D7.2, R10.2
VCC: J5.1, J5.2, J5.3, J5.4, J5.5, J5.6, J5.7, J5.8, J5.9, J5.10, J5.11, J5.12, J5.13, J5.14, J5.15, J5.16, J5.17, J5.18, JP1.2 (C), R14.1, R16.1, R18.1, R20.1, R22.1, R24.1, R26.1, R28.1, R31.1, R32.1, R35.1, R36.1, R39.1, R40.1, R43.1, R44.1, R46.1, R48.1

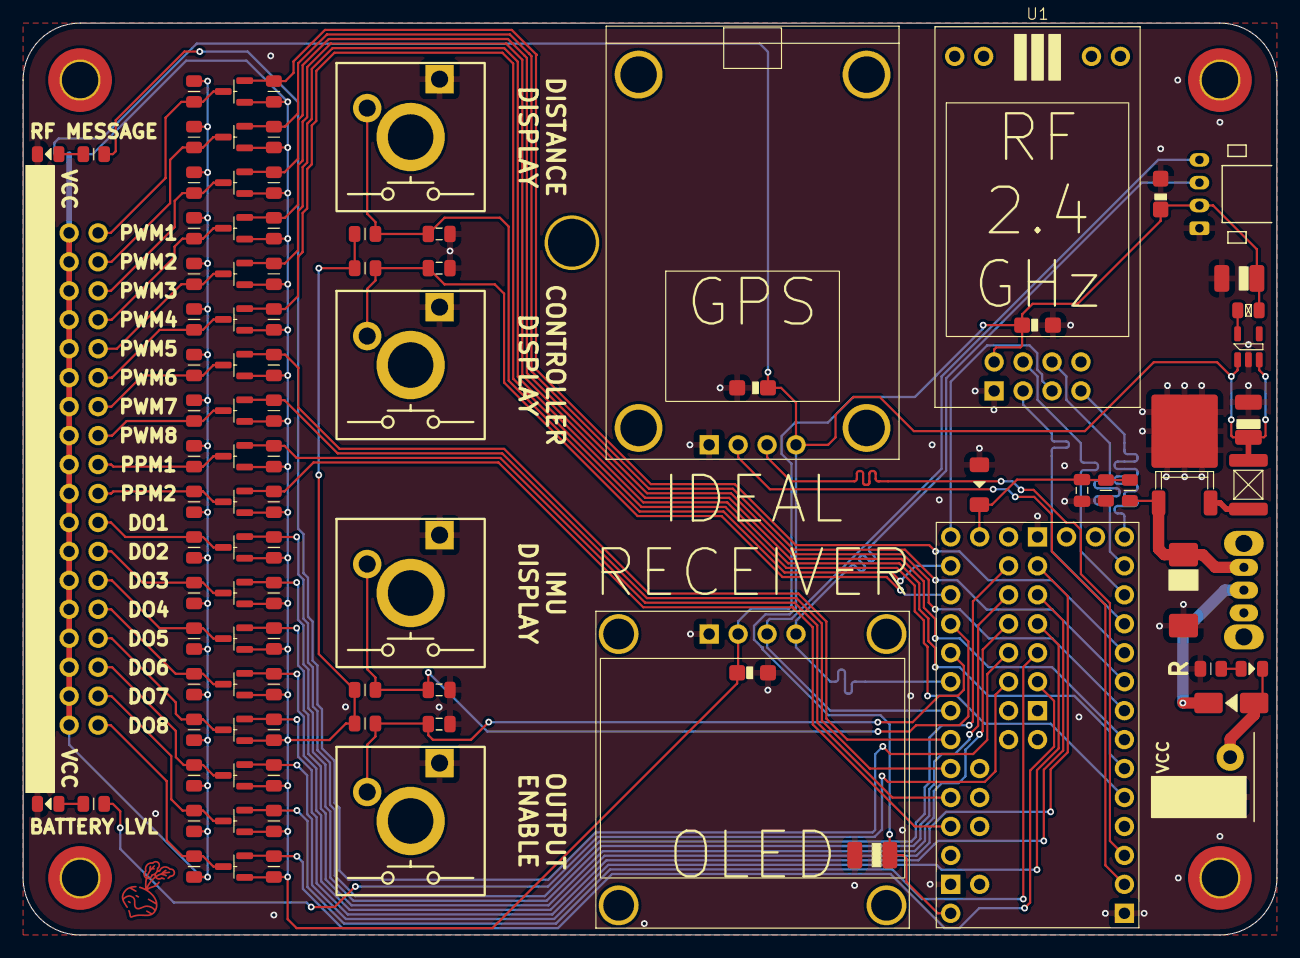
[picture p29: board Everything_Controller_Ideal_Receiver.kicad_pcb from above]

Board: 2 copper layers, 110.0 x 80.0 mm, 100 parts (1 on the bottom side), 64 nets.

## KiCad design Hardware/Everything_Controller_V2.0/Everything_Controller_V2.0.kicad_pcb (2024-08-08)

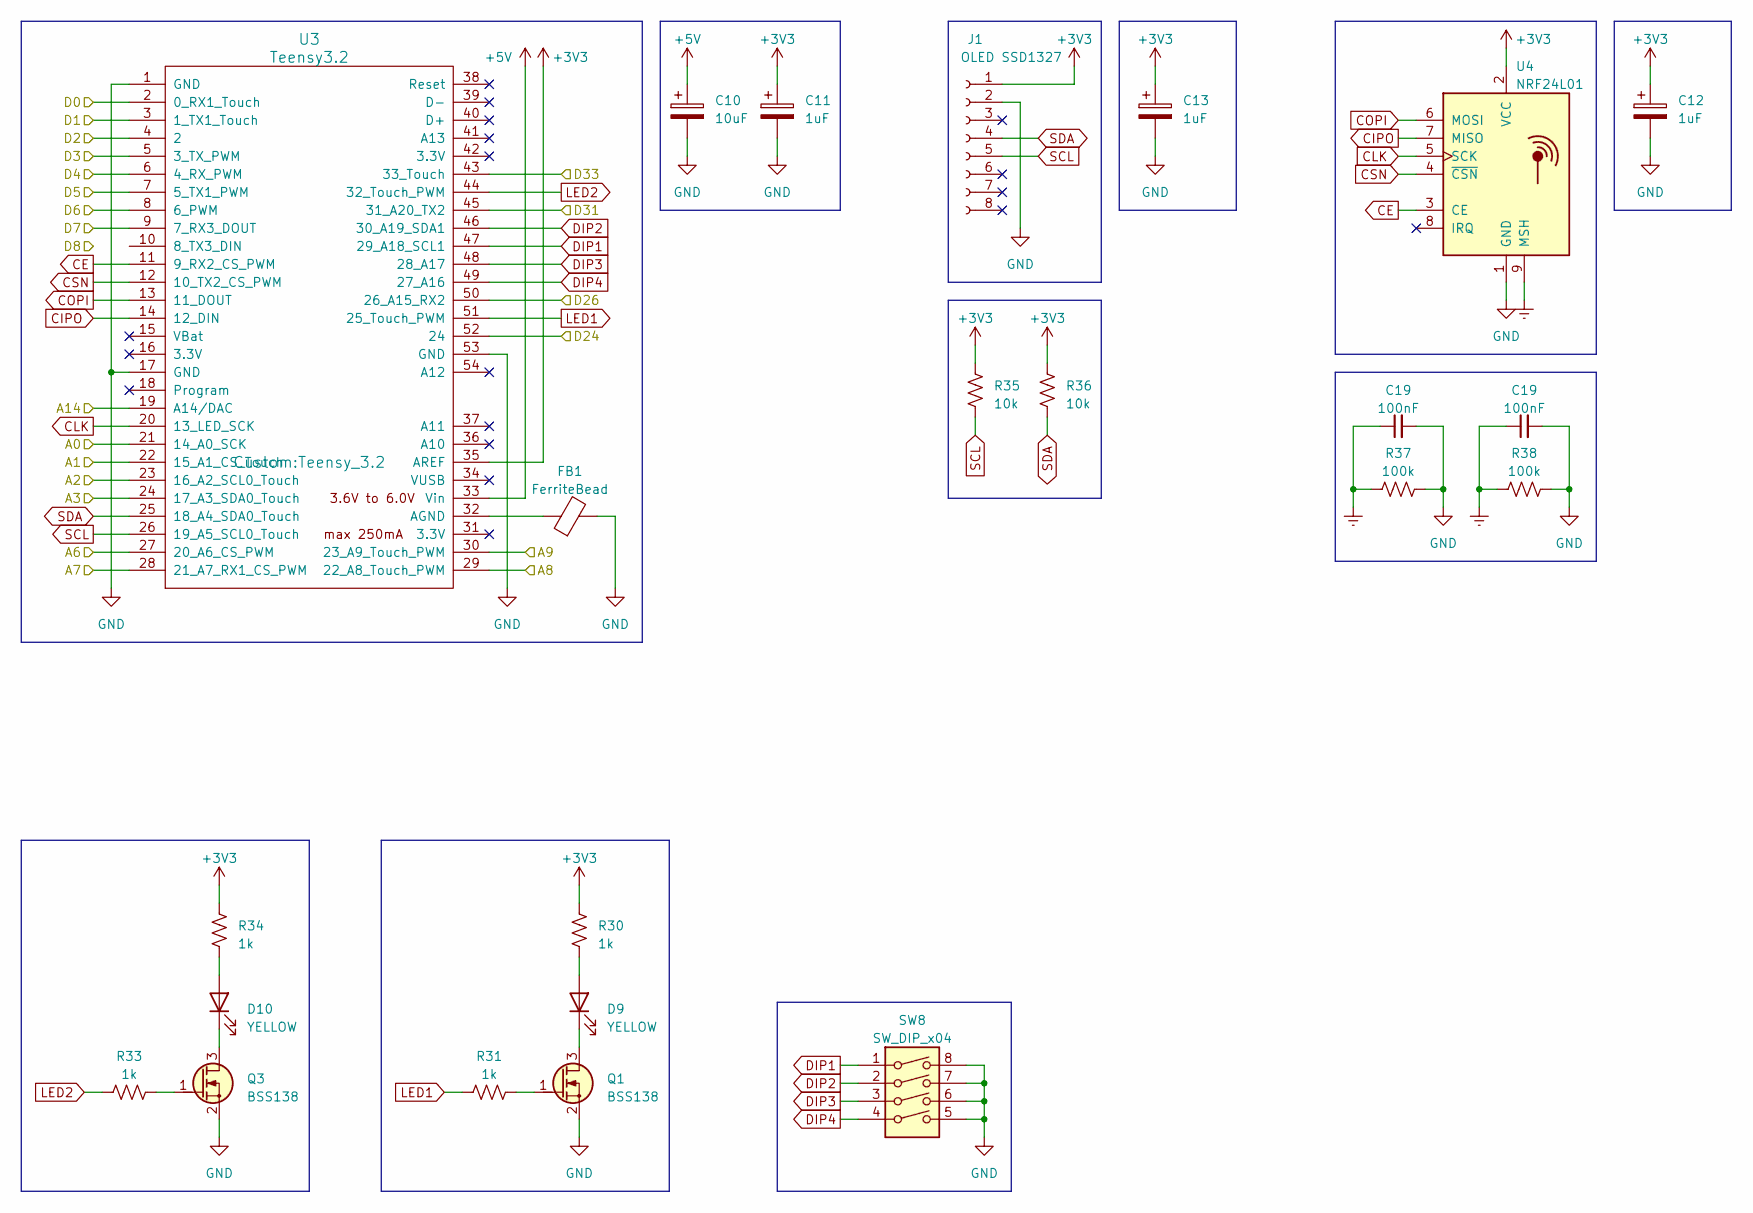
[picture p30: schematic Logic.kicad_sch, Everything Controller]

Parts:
C10: 10uF; CP_EIA-3216-18_Kemet-A
C11, C12, C13: 1uF; CP_EIA-3216-18_Kemet-A
C19: 100nF; C_0805_2012Metric
D9, D10: YELLOW; LED_0805_2012Metric
FB1: FerriteBead; L_0805_2012Metric
J1: OLED SSD1327; SSD1327_Breakout
Q1, Q3: BSS138; SOT-23
R30, R31, R33, R34: 1k; R_0805_2012Metric
R35, R36: 10k; R_0805_2012Metric
R37, R38: 100k; R_0805_2012Metric
SW8: SW_DIP_x04; SW_DIP_SPSTx04_Slide_Omron_A6S-410x_W8.9mm_P2.54mm
U3: Teensy3.2; Teensy_3.2
U4: NRF24L01; EByte_NRF24L01_Breakout

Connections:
+3V3: C11.1, C12.1, C13.1, J1.1, R30.1, R34.1, R35.1, R36.1, U3.35 (AREF), U4.2 (VCC); also elsewhere on the board
+5V: C10.1, U3.33 (Vin); also elsewhere on the board
/Inputs/BT1: U3.45 (31_A20_TX2); also elsewhere on the board
/Inputs/BT2: U3.52 (24); also elsewhere on the board
/Inputs/BT3: U3.50 (26_A15_RX2); also elsewhere on the board
/Inputs/BT4: U3.43 (33_Touch); also elsewhere on the board
/Inputs/CLK1: U3.9 (7_RX3_DOUT); also elsewhere on the board
/Inputs/CLK2: U3.6 (4_RX_PWM); also elsewhere on the board
/Inputs/DT1: U3.8 (6_PWM); also elsewhere on the board
/Inputs/DT2: U3.7 (5_TX1_PWM); also elsewhere on the board
/Inputs/E_BT1: U3.5 (3_TX_PWM); also elsewhere on the board
/Inputs/E_BT2: U3.4 (2); also elsewhere on the board
/Inputs/J_BT1: U3.2 (0_RX1_Touch); also elsewhere on the board
/Inputs/J_BT2: U3.3 (1_TX1_Touch); also elsewhere on the board
/Inputs/POT1: U3.22 (15_A1_CS_Touch); also elsewhere on the board
/Inputs/POT3: U3.23 (16_A2_SCL0_Touch); also elsewhere on the board
/Inputs/POT4: U3.21 (14_A0_SCK); also elsewhere on the board
/Inputs/X_AX1: U3.27 (20_A6_CS_PWM); also elsewhere on the board
/Inputs/X_AX2: U3.30 (23_A9_Touch_PWM); also elsewhere on the board
/Inputs/Y_AX1: U3.28 (21_A7_RX1_CS_PWM); also elsewhere on the board
/Inputs/Y_AX2: U3.29 (22_A8_Touch_PWM); also elsewhere on the board
/Logic/A14: U3.19 (A14/DAC); also elsewhere on the board
CE: U3.11 (9_RX2_CS_PWM), U4.3 (CE)
CIPO: U3.14 (12_DIN), U4.7 (MISO)
CLK: U3.20 (13_LED_SCK), U4.5 (SCK)
COPI: U3.13 (11_DOUT), U4.6 (MOSI)
CSN: U3.12 (10_TX2_CS_PWM), U4.4 (~CSN)
DIP1: SW8.1, U3.47 (29_A18_SCL1)
DIP2: SW8.2, U3.46 (30_A19_SDA1)
DIP3: SW8.3, U3.48 (28_A17)
DIP4: SW8.4, U3.49 (27_A16)
GND: C10.2, C11.2, C12.2, C13.2, C19.2, FB1.2, J1.2, Q1.2 (S), Q3.2 (S), R37.2, R38.2, SW8.5, SW8.6, SW8.7, SW8.8, U3.1 (GND), U3.17 (GND), U3.53 (GND), U4.1 (GND); also elsewhere on the board
LED1: R31.1, U3.51 (25_Touch_PWM)
LED2: R33.1, U3.44 (32_Touch_PWM)
unnamed: D9.2 (A), R30.2
unnamed: D9.1 (K), Q1.3 (D)
unnamed: D10.2 (A), R34.2
unnamed: D10.1 (K), Q3.3 (D)
unnamed: Q1.1 (G), R31.2
unnamed: Q3.1 (G), R33.2
unnamed: FB1.1, U3.32 (AGND)
SCL: J1.5, R35.2, U3.26 (19_A5_SCL0_Touch)
SDA: J1.4, R36.2, U3.25 (18_A4_SDA0_Touch)

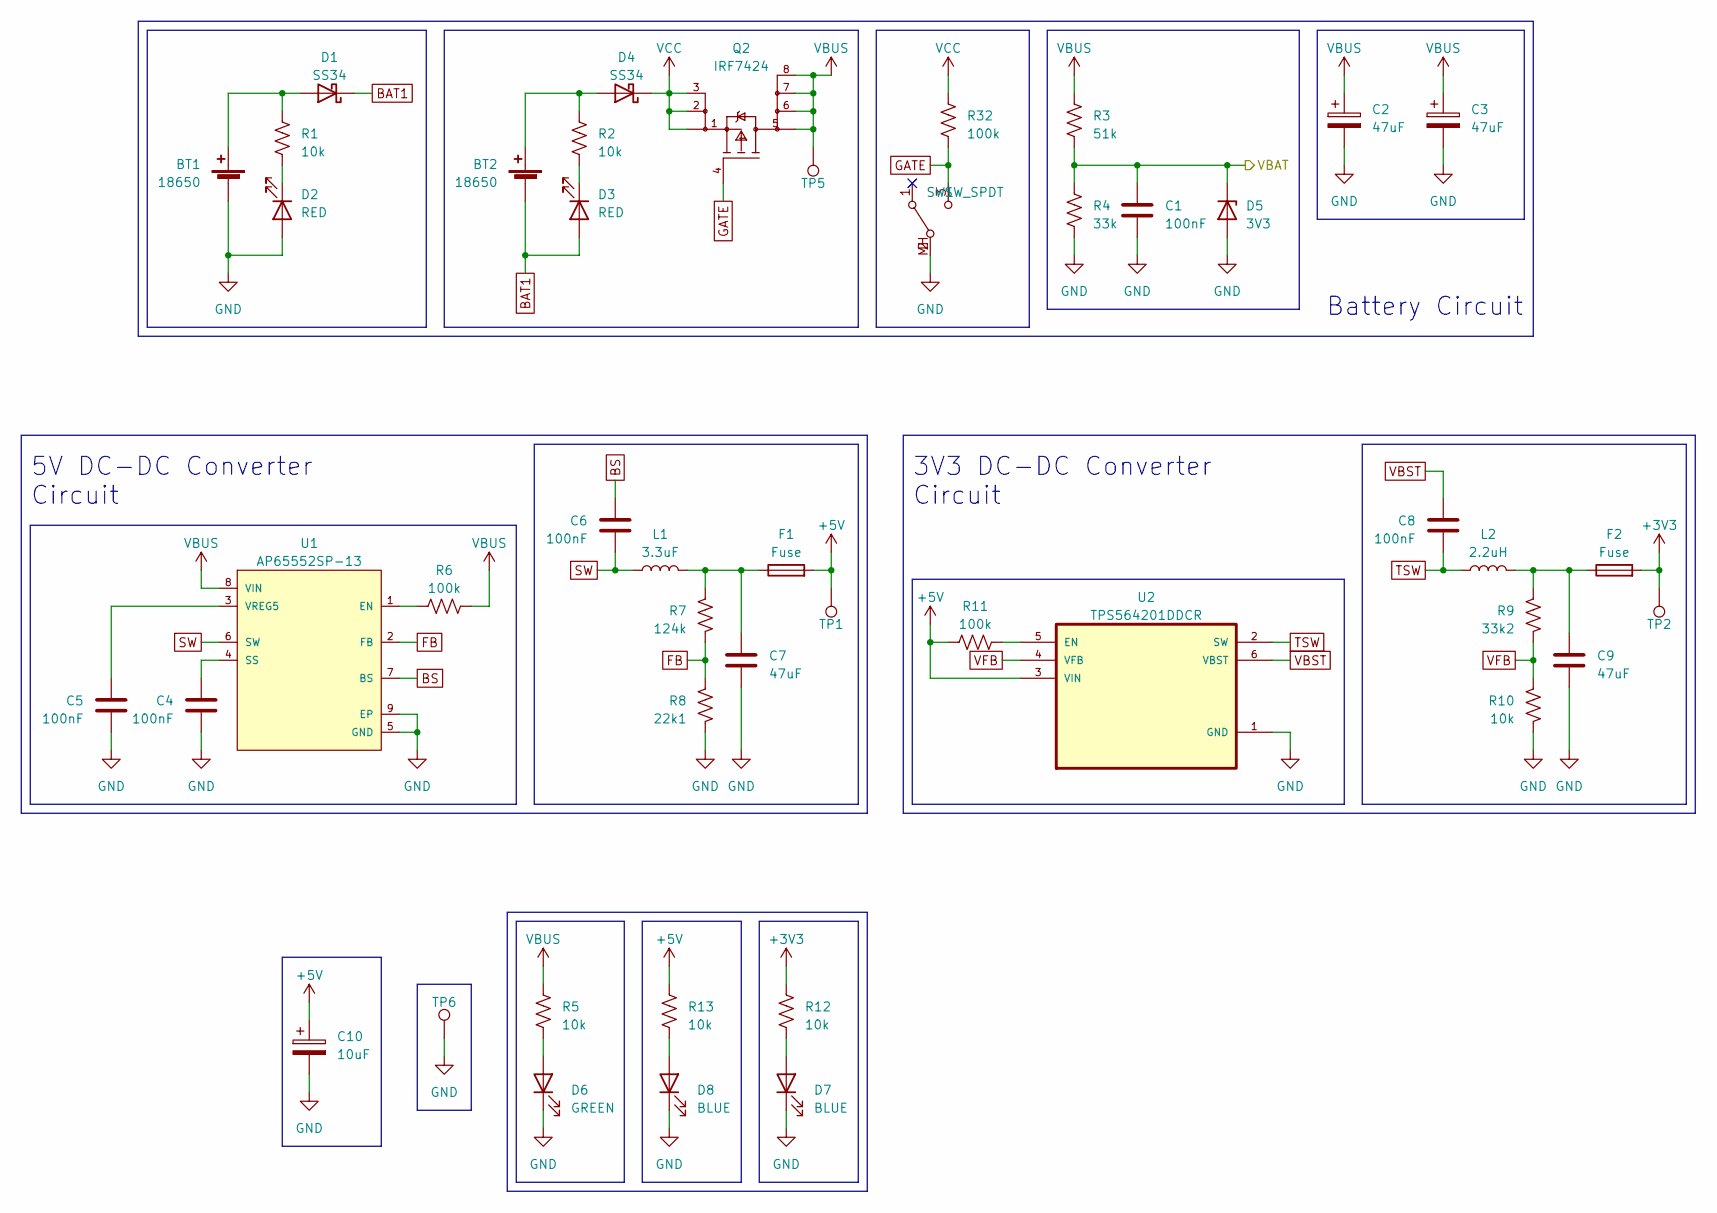
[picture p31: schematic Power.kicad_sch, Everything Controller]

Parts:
BT1, BT2: 18650; TerminalBlock_4Ucon_1x02_P3.50mm_Horizontal
C1, C4, C5, C6, C8: 100nF; C_0805_2012Metric
C2, C3: 47uF; CP_EIA-7343-31_Kemet-D
C7, C9: 47uF; C_1210_3225Metric
C10: 10uF; CP_EIA-3528-21_Kemet-B
D1, D4: SS34; D_SMA
D2, D3: RED; LED_0805_2012Metric
D5: 3V3; D_MiniMELF
D6: GREEN; LED_0805_2012Metric
D7, D8: BLUE; LED_0805_2012Metric
F1, F2: Fuse; Fuse_1206_3216Metric
L1: 3.3uF; L_1210_3225Metric
L2: 2.2uH; L_1210_3225Metric
Q2: IRF7424; Infineon-PG-DSO-8-11_2006-902-MFG
R1, R2, R5, R10, R12, R13: 10k; R_0805_2012Metric
R3: 51k; R_0805_2012Metric
R4: 33k; R_0805_2012Metric
R6, R11, R32: 100k; R_0805_2012Metric
R7: 124k; R_0805_2012Metric
R8: 22k1; R_0805_2012Metric
R9: 33k2; R_0805_2012Metric
SW1: SW_SPDT; SW_Slide_1P2T_CK_OS102011MS2Q
TP1, TP2, TP5, TP6: TestPoint; TestPoint_Pad_D1.5mm
U1: AP65552SP-13; Diodes-AP65552SP-13-06_2015-0-0
U2: TPS564201DDCR; Texas_Instruments-DDC_R-PDSO-G6-0-0-0

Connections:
+3V3: F2.2, R12.2, TP2.1; also elsewhere on the board
+5V: C10.1, F1.2, R11.2, R13.2, TP1.1, U2.3 (VIN); also elsewhere on the board
/Logic/A14: C1.1, D5.1 (K), R3.2, R4.1; also elsewhere on the board
BAT1: BT2.2 (-), D1.1 (K), D3.2 (A)
BS: C6.1, U1.7 (BS)
FB: R7.2, R8.1, U1.2 (FB)
GATE: Q2.4 (G), R32.2, SW1.3 (C)
GND: BT1.2 (-), C1.2, C2.2, C3.2, C4.2, C5.2, C7.2, C9.2, C10.2, D2.2 (A), D5.2 (A), D6.1 (K), D7.1 (K), D8.1 (K), R4.2, R8.2, R10.2, SW1.2 (B), SW1.MH (B), TP6.1, U1.5 (GND), U1.9 (EP), U2.1 (GND); also elsewhere on the board
unnamed: BT1.1 (+), D1.2 (A), R1.1
unnamed: BT2.1 (+), D4.2 (A), R2.1
unnamed: C7.1, F1.1, L1.2, R7.1
unnamed: C9.1, F2.1, L2.2, R9.1
unnamed: D2.1 (K), R1.2
unnamed: D3.1 (K), R2.2
unnamed: D6.2 (A), R5.1
unnamed: D7.2 (A), R12.1
unnamed: D8.2 (A), R13.1
unnamed: R6.2, U1.1 (EN)
unnamed: C4.1, U1.4 (SS)
unnamed: C5.1, U1.3 (VREG5)
unnamed: R11.1, U2.5 (EN)
SW: C6.2, L1.1, U1.6 (SW)
TSW: C8.2, L2.1, U2.2 (SW)
VBST: C8.1, U2.6 (VBST)
VBUS: C2.1, C3.1, Q2.5 (D), Q2.6 (D), Q2.7 (D), Q2.8 (D), R3.1, R5.2, R6.1, TP5.1, U1.8 (VIN)
VCC: D4.1 (K), Q2.1 (S), Q2.2 (S), Q2.3 (S), R32.1
VFB: R9.2, R10.1, U2.4 (VFB)

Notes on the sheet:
5V DC-DC Converter Circuit
Battery Circuit
3V3 DC-DC Converter Circuit

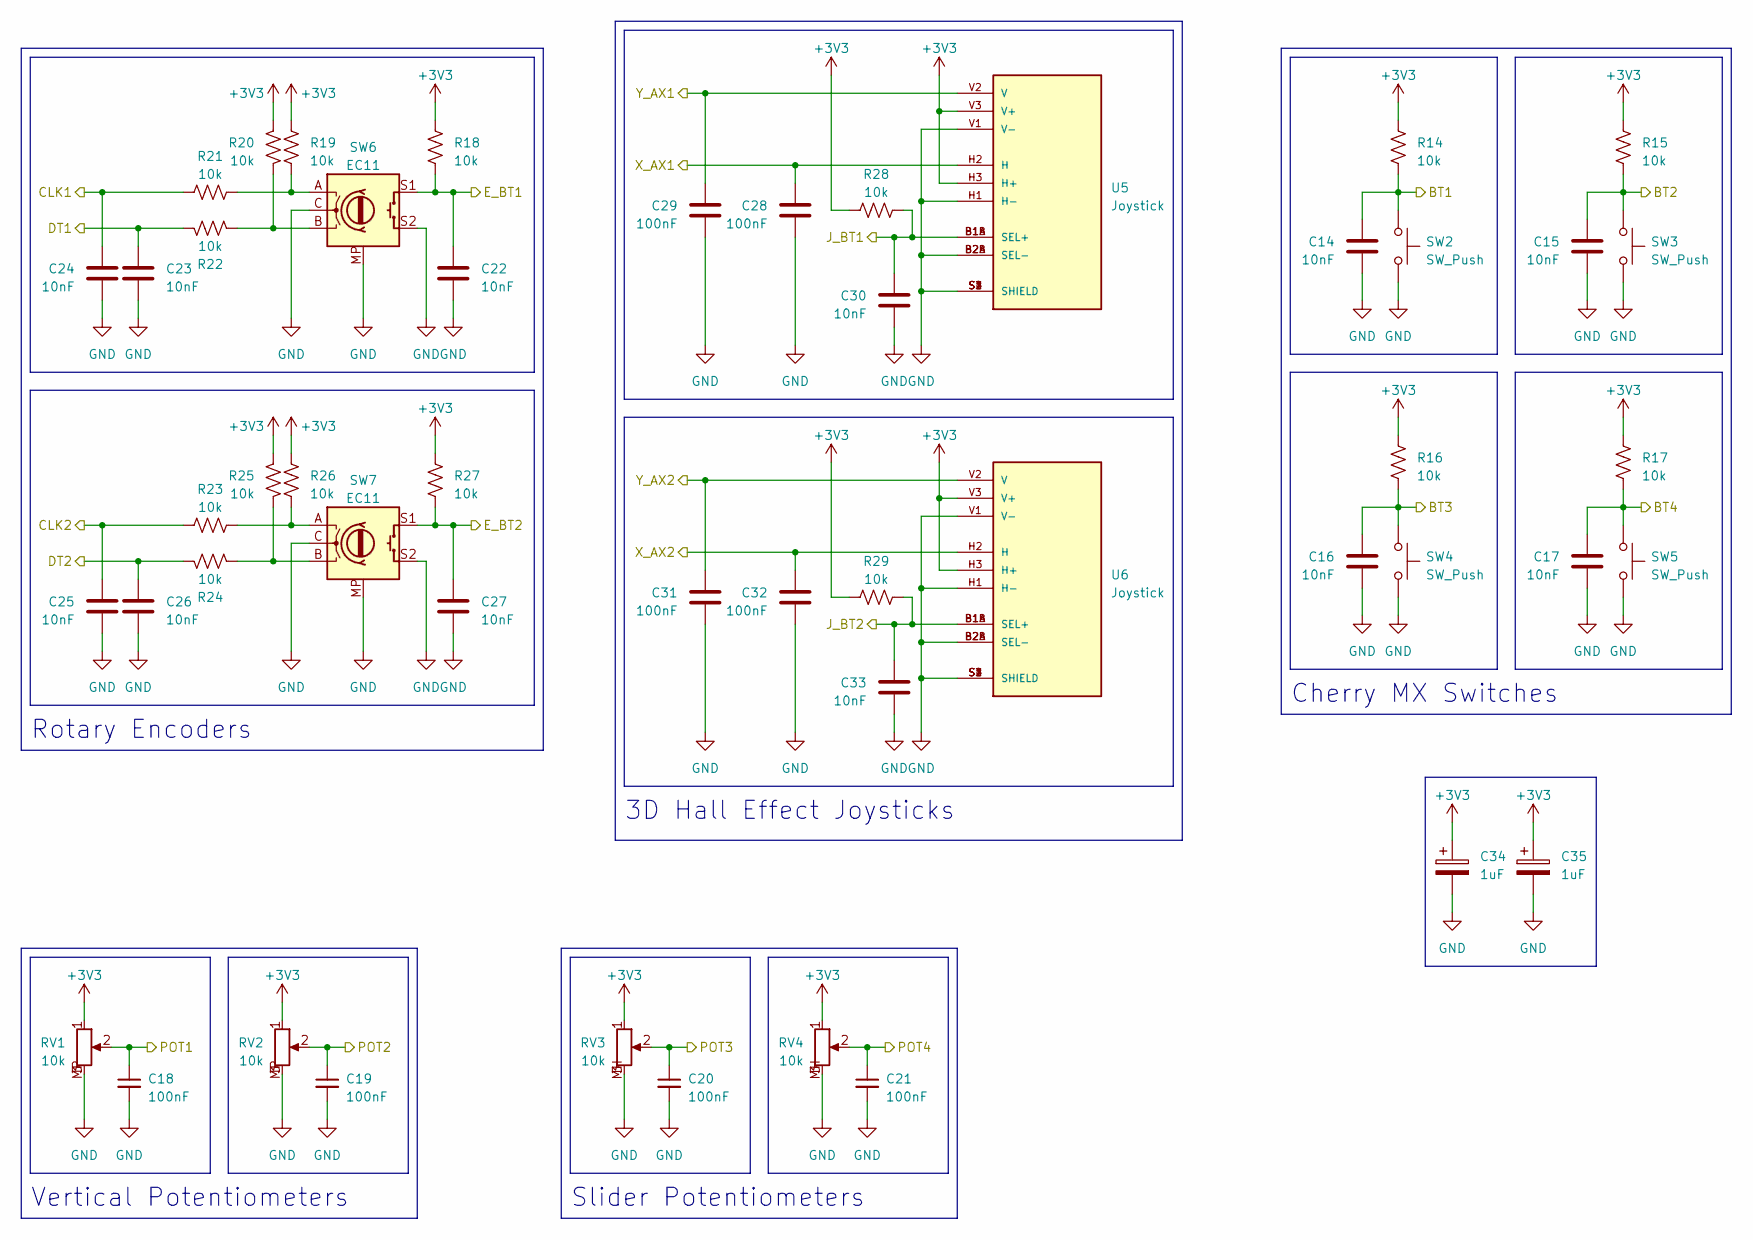
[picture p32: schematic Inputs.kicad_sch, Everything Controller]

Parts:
C14, C15, C16, C17, C22, C23, C24, C25, C26, C27, C30, C33: 10nF; C_0805_2012Metric
C18, C19, C20, C21, C28, C29, C31, C32: 100nF; C_0805_2012Metric
C34, C35: 1uF; CP_EIA-3216-18_Kemet-A
R14, R15, R16, R17, R18, R19, R20, R21, R22, R23, R24, R25, R26, R27, R28, R29: 10k; R_0805_2012Metric
RV1, RV2: 10k; Potentiometer_Alps_RK09K_Single_Vertical
RV3, RV4: 10k; RS30111A602N
SW2, SW3, SW4, SW5: SW_Push; SW_Cherry_MX_Plate
SW6, SW7: EC11; RotaryEncoder_Alps_EC11E_Vertical_H20mm
U5, U6: Joystick; XDCR_COM-09032

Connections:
+3V3: C34.1, C35.1, R14.1, R15.1, R16.1, R17.1, R18.1, R19.1, R20.1, R25.1, R26.1, R27.1, R28.1, R29.1, RV1.1, RV2.1, RV3.1, RV4.1, U5.H3 (H+), U5.V3 (V+), U6.H3 (H+), U6.V3 (V+); also elsewhere on the board
/Inputs/BT1: C14.1, R14.2, SW2.1; also elsewhere on the board
/Inputs/BT2: C15.1, R15.2, SW3.1; also elsewhere on the board
/Inputs/BT3: C16.1, R16.2, SW4.1; also elsewhere on the board
/Inputs/BT4: C17.1, R17.2, SW5.1; also elsewhere on the board
/Inputs/CLK1: C24.1, R21.1; also elsewhere on the board
/Inputs/CLK2: C25.1, R23.1; also elsewhere on the board
/Inputs/DT1: C23.1, R22.1; also elsewhere on the board
/Inputs/DT2: C26.1, R24.1; also elsewhere on the board
/Inputs/E_BT1: C22.1, R18.2, SW6.S1; also elsewhere on the board
/Inputs/E_BT2: C27.1, R27.2, SW7.S1; also elsewhere on the board
/Inputs/J_BT1: C30.1, R28.2, U5.B1A (SEL+), U5.B1B (SEL+); also elsewhere on the board
/Inputs/J_BT2: C33.1, R29.2, U6.B1A (SEL+), U6.B1B (SEL+); also elsewhere on the board
/Inputs/POT1: C18.1, RV1.2; also elsewhere on the board
/Inputs/POT3: C20.1, RV3.2; also elsewhere on the board
/Inputs/POT4: C21.1, RV4.2; also elsewhere on the board
/Inputs/X_AX1: C28.1, U5.H2 (H); also elsewhere on the board
/Inputs/X_AX2: C32.1, U6.H2 (H); also elsewhere on the board
/Inputs/Y_AX1: C29.1, U5.V2 (V); also elsewhere on the board
/Inputs/Y_AX2: C31.1, U6.V2 (V); also elsewhere on the board
GND: C14.2, C15.2, C16.2, C17.2, C18.2, C19.2, C20.2, C21.2, C22.2, C23.2, C24.2, C25.2, C26.2, C27.2, C28.2, C29.2, C30.2, C31.2, C32.2, C33.2, C34.2, C35.2, RV1.3, RV1.MP (3), RV2.3, RV2.MP (3), RV3.3, RV3.MH (3), RV4.3, RV4.MH (3), SW2.2, SW3.2, SW4.2, SW5.2, SW6.C, SW6.MP, SW6.S2, SW7.C, SW7.MP, SW7.S2, U5.B2A (SEL-), U5.B2B (SEL-), U5.H1 (H-), U5.S1 (SHIELD), U5.S2 (SHIELD), U5.S3 (SHIELD), U5.S4 (SHIELD), U5.V1 (V-), U6.B2A (SEL-), U6.B2B (SEL-), U6.H1 (H-), U6.S1 (SHIELD), U6.S2 (SHIELD), U6.S3 (SHIELD), U6.S4 (SHIELD), U6.V1 (V-); also elsewhere on the board
unnamed: R19.2, R21.2, SW6.A
unnamed: R20.2, R22.2, SW6.B
unnamed: R23.2, R26.2, SW7.A
unnamed: R24.2, R25.2, SW7.B

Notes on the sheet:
Slider Potentiometers
Cherry MX Switches
Vertical Potentiometers
Rotary Encoders
3D Hall Effect Joysticks

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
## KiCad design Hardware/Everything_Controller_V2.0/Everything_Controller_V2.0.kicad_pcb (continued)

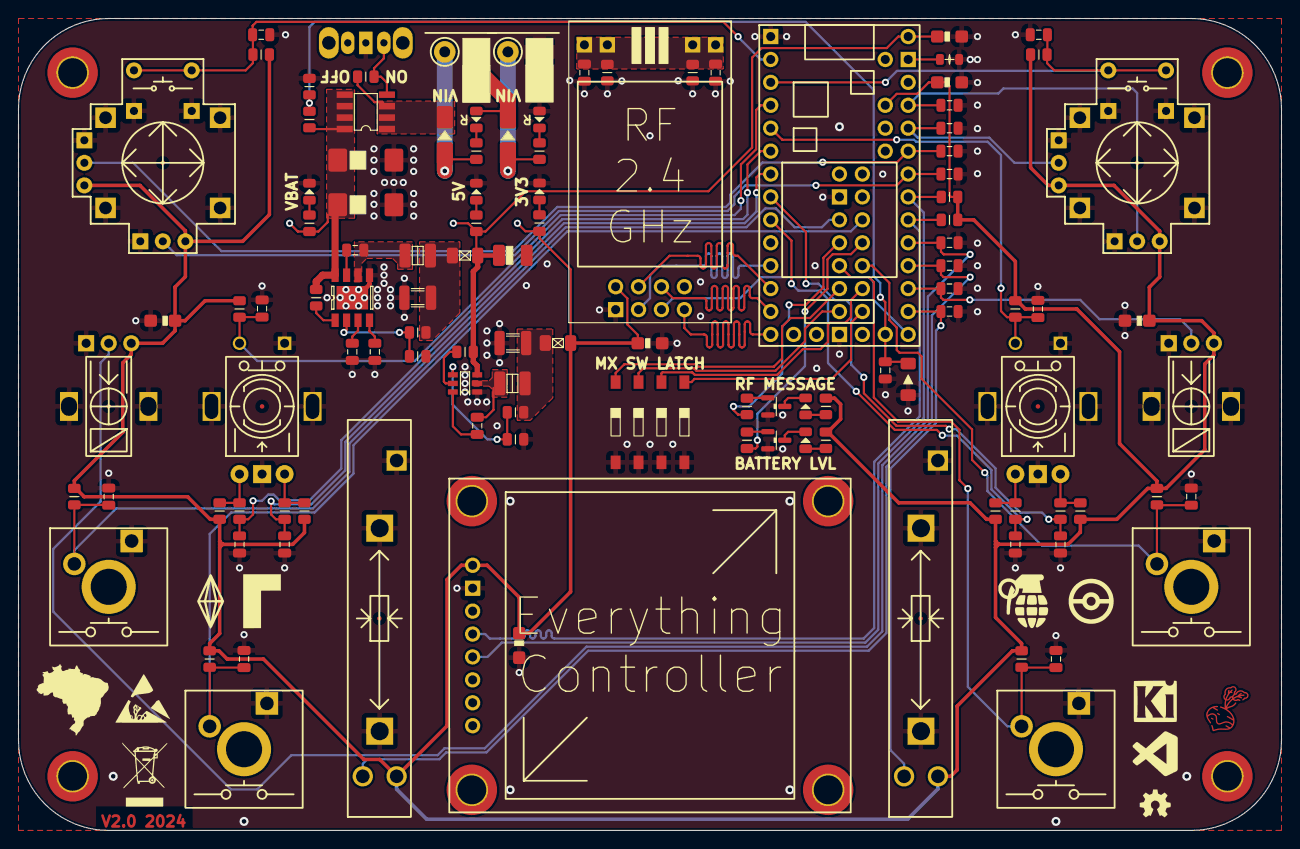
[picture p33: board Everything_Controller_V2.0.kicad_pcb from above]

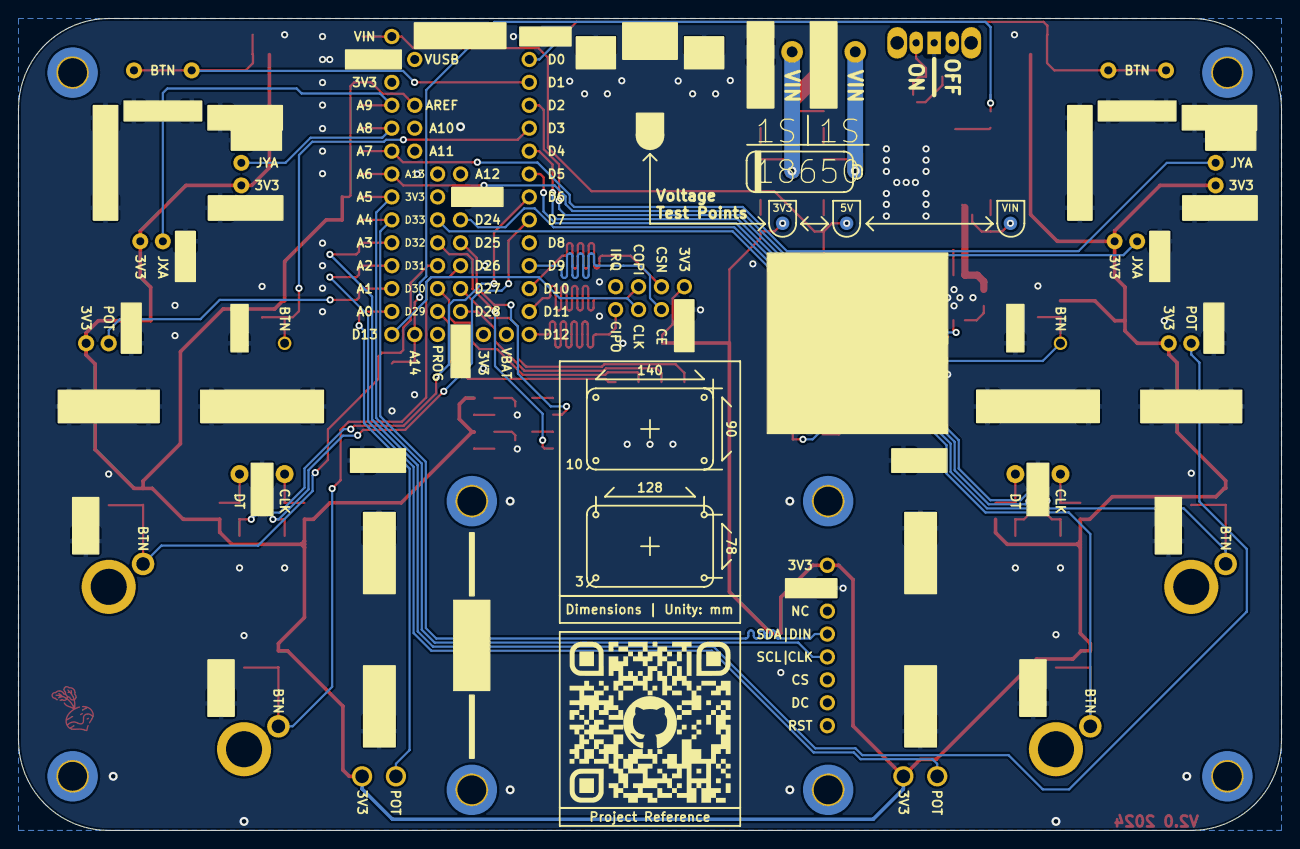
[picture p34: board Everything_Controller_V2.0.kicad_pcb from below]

Board: 2 copper layers, 140.0 x 90.0 mm, 119 parts (4 on the bottom side), 72 nets.

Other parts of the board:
C36: 10uF; CP_EIA-3528-21_Kemet-B
C37, C38: 100nF; C_0805_2012Metric

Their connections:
+5V: C36.1; also elsewhere on the board
GND: C36.2, C37.2, C38.2; also elsewhere on the board

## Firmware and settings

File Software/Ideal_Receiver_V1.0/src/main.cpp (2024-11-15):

/**************************************************************
 * Everything Controller (v2.0)
 *
 * Base code for the "Everything Controller V2.0" to send data to a receiver.
 * Communication is based on RF24 using the NRF24L01+ module. The controller
 * sends data from 8 digital buttons, 2 joysticks (2 X-axis and 2 Y-axis),
 * two sliders, two rotary potentiometers and two rotary encoders.
 * With this data, it is possible to control anything.
 *
 * Written by Giovanni de Castro (10/03/2024).
 *************************************************************/

// ********************** Project Libraries *******************
// Arduino framework
#include <Arduino.h>

// NRF24L01 control libraries
#include <SPI.h>
#include <RF24.h>

// SSD1306 control libraries
#include <Adafruit_GFX.h>
#include <Adafruit_SSD1306.h>

// BME680 libraries
#include <Adafruit_Sensor.h>
#include <Adafruit_BME680.h>

// Servo control library
#include <PWMServo.h>
#include <Servo.h>

// Button library
#include <Bounce2.h>

// GPS library
#include <TinyGPS++.h>

// Teensy ADC libraries
#include <ADC.h>
#include <ADC_util.h>

// ********************** Project Macros **********************
// Macro to disable or enable serial debugging
// #define DEBUG_ANALOG
// #define DEBUG_DIGITAL
// #define DEBUG_ENCODER
// #define DEBUG_BUTTONS
// #define DEBUG_AMBIENT
// #define DEBUG_GPS
// #define DEBUG_BATTERY

// PWM output pins configuration
#define PIN_PWM1 8
#define PIN_PWM2 7
#define PIN_PWM3 6
#define PIN_PWM4 5
#define PIN_PWM5 4
#define PIN_PWM6 3
#define PIN_PWM7 20
#define PIN_PWM8 21

// PPM output pins configuration
#define PIN_PPM1 22
#define PIN_PPM2 23

// Digital output pins configuration
#define PIN_DOUT1 29
#define PIN_DOUT2 30
#define PIN_DOUT3 31
#define PIN_DOUT4 28
#define PIN_DOUT5 27
#define PIN_DOUT6 26
#define PIN_DOUT7 25
#define PIN_DOUT8 24

// LED output pins configuration
#define PIN_LED1 32
#define PIN_LED2 33

// Buttons pins configuration
#define PIN_BTN1 14
#define PIN_BTN2 15
#define PIN_BTN3 16
#define PIN_BTN4 17

// NRF24L01 pins definitions
#define PIN_CE 9
#define PIN_CSN 10

// SSD1306 display definitions
#define DISPLAY_WIDTH 128
#define DISPLAY_HEIGHT 64
#define DISPLAY_ADDRESS 0x3C
#define DISPLYA_RESET -1

// ********************** Project Objects *********************
// Teensy analog pins object
ADC *adc = new ADC();

// NRF24L01 control object
RF24 radio(PIN_CE, PIN_CSN);

// SSD1306 display control object
Adafruit_SSD1306 display(DISPLAY_WIDTH, DISPLAY_HEIGHT, &Wire, DISPLYA_RESET);

// BME680 control object
Adafruit_BME680 ambient(&Wire);

// Servo control objects
PWMServo SERVOS[2];

// The TinyGPSPlus object
TinyGPSPlus gps;

// ********************** Project Variables *******************
// PWM pins definitions
const uint8_t NUMBER_PWM = 8;
const uint8_t PWM_PINS[NUMBER_PWM] = {PIN_PWM1, PIN_PWM2, PIN_PWM3, PIN_PWM4, PIN_PWM5, PIN_PWM6, PIN_PWM7, PIN_PWM8};
uint8_t PWM_OUT[NUMBER_PWM] = {0, 0, 0, 0, 0, 0, 0, 0};

// PPM pins definitions
const uint8_t NUMBER_PPM = 2;
const uint8_t PPM_PINS[NUMBER_PPM] = {PIN_PPM1, PIN_PPM2};
uint16_t PPM_OUT[NUMBER_PPM] = {90, 90};

// Digital pins definitions
const uint8_t NUMBER_DOUTS = 8;
const uint8_t DOUT_PINS[NUMBER_DOUTS] = {PIN_DOUT1, PIN_DOUT2, PIN_DOUT3, PIN_DOUT4, PIN_DOUT5, PIN_DOUT6, PIN_DOUT7, PIN_DOUT8};
bool DOUT_OUT[NUMBER_DOUTS] = {0, 0, 0, 0, 0, 0, 0, 0};

// LEDs Pins
const uint8_t NUMBER_LEDS = 2;
const uint8_t LED_PINS[NUMBER_LEDS] = {PIN_LED1, PIN_LED2};

// Controller buttons objects
const uint8_t NUMBER_BUTTONS = 4;
const uint8_t DEBOUNCE_INTERVAL = 50;
Bounce BUTTONS[NUMBER_BUTTONS];
const uint8_t PINS_BUTTONS[NUMBER_BUTTONS] = {PIN_BTN1, PIN_BTN2, PIN_BTN3, PIN_BTN4};
bool buttons_readings[NUMBER_BUTTONS] = {LOW, LOW, LOW, LOW};
bool last_buttons_readings[NUMBER_BUTTONS] = {HIGH, HIGH, HIGH, HIGH};

// Radio address and channel
const uint8_t radio_CHANNEL = 71;
const uint8_t radio_ADDRESSES[2][6] = {{0xB6, 0xE9, 0x00, 0x7A, 0x43}, {0x10, 0xCA, 0x87, 0x3F, 0xD8}};
const bool radio_NUMBER = 1;

// Message receiving variables
uint8_t channel;
uint8_t bytes;
unsigned long last_message = 0;
const uint16_t RX_TIMEOUT = 2500; // [ms]

// Variables for display timing
unsigned long display_time = 0;
const uint16_t UPDATE_INTERVAL = 25; // [ms]

// Ambient sensor variables
const float sea_level_pressure = 1013.25; // [hpa]
float temperature_reading = 0.0;
float humidity_reading = 0.0;
float pressure_reading = 0.0;
float air_quality_reading = 0.0;
float altitude_reading = 0.0;
String temperature_str;
String humidity_str;
String pressure_str;
String altitude_str;
unsigned long ambient_time = 0;
const uint16_t READING_INTERVAL = 1000; // [ms]

// Distance reference variables
double reference_lng = 0;
double reference_lat = 0;
double new_lng = 0;
double new_lat = 0;
float distance = 0;
bool update_reference = true;
unsigned long gps_time = 0;
const uint16_t GPS_INTERVAL = 1000; // [ms]

// Battery Voltage Divider Variables
const uint8_t BATTERY_PIN = A14;
float VD_VOUT = 0.0;
float VD_VIN = 0.0;
float last_VD_VIN = 0.0;
const float VD_R1 = 51000.0;
const float VD_R2 = 33000.0;
const float MIN_VIN = 6.5;
const float HYSTERESIS = 0.1;
unsigned long last_battery = 5000;
const uint16_t BATTERY_READING = 5000; // [ms]
uint8_t battery_icon = 4;
uint8_t last_battery_icon = 0;

// Controller variables structure
typedef struct
{
  bool buttons_message[8];
  uint16_t analogs_message[8];
  int16_t encoders_messsage[2];
} controller_variables;
controller_variables controller;
enum ANALOG_MESSAGE
{
  JOY_XL,
  JOY_YL,
  JOY_XR,
  JOY_YR,
  ROT_L,
  ROT_R,
  SLI_L,
  SLI_R
};
enum BUTTONS_MESSAGE
{
  JOY_L,
  JOY_R,
  ENC_L,
  ENC_R,
  MX_EL,
  MX_CL,
  MC_CR,
  MX_ER
};
enum ENCODERS_MESSAGE
{
  LEFT,
  RIGHT
};

// ********************** Project Functions *******************
// Display controller button state
void drawButtonState(int x, int y, int width, int height, bool state)
{
  display.drawRoundRect(x, y, width, height, 5, WHITE);
  if (state)
  {
    display.fillRoundRect(x + 2, y + 2, width - 4, height - 4, 2, WHITE);
  }
}

// Display controller joystick position
void drawJoyPosition(int x, int y, int radius, int px, int py)
{
  display.drawLine(x, (y + radius) - 4, x, (y - radius) + 4, WHITE);
  display.drawLine((x + radius) - 4, y, (x - radius) + 4, y, WHITE);
  display.drawRoundRect(x - radius, y - radius, (radius * 2) + 1, (radius * 2) + 1, 5, WHITE);
  display.drawCircle(x, y, radius, WHITE);
  display.fillCircle(px, py, radius / 10, WHITE);
}

// Display controller potentiometer position
void drawPottentiometerBar(int x, int y, int width, int height, int progress)
{
  float bar = ((float)(height - 4) / 100) * progress;
  display.drawRoundRect(x, y, width, height, 5, WHITE);
  display.fillRoundRect(x + 2, y + 2, width - 4, height - 4, 2, WHITE);
  display.fillRoundRect(x + 2, y + 2, width - 4, bar, 2, BLACK);
}

// Function to display all controller inputs
void display_controller()
{
  display.clearDisplay();
  drawJoyPosition(22, 22, 22, map(controller.analogs_message[JOY_XL], 0, 4095, 2, 42), map(controller.analogs_message[JOY_YL], 0, 4095, 2, 42));
  drawPottentiometerBar(46, 0, 6, 44, map(controller.analogs_message[ROT_L], 0, 4095, 0, 100));
  drawPottentiometerBar(54, 0, 6, 44, map(controller.analogs_message[SLI_L], 0, 4095, 100, 0));
  drawPottentiometerBar(61, 0, 6, 22, map(controller.encoders_messsage[LEFT], -90, 90, 0, 100));
  drawPottentiometerBar(61, 22, 6, 22, map(controller.encoders_messsage[RIGHT], -90, 90, 0, 100));
  drawPottentiometerBar(68, 0, 6, 44, map(controller.analogs_message[SLI_R], 0, 4095, 100, 0));
  drawPottentiometerBar(76, 0, 6, 44, map(controller.analogs_message[ROT_R], 0, 4095, 0, 100));
  drawJoyPosition(105, 22, 22, map(controller.analogs_message[JOY_XR], 0, 4095, 86, 126), map(controller.analogs_message[JOY_YR], 0, 4095, 2, 42));
  drawButtonState(0, 46, 32, 8, !controller.buttons_message[JOY_L]);
  drawButtonState(32, 46, 32, 8, !controller.buttons_message[ENC_L]);
  drawButtonState(64, 46, 32, 8, !controller.buttons_message[ENC_R]);
  drawButtonState(96, 46, 32, 8, !controller.buttons_message[JOY_R]);
  drawButtonState(0, 56, 32, 8, !controller.buttons_message[MX_EL]);
  drawButtonState(32, 56, 32, 8, !controller.buttons_message[MX_CL]);
  drawButtonState(64, 56, 32, 8, !controller.buttons_message[MC_CR]);
  drawButtonState(96, 56, 32, 8, !controller.buttons_message[MX_ER]);
  display.display();
}

// Function to display ambient readings
void display_ambient()
{
  display.clearDisplay();
  display.setTextSize(2);
  display.setTextColor(SSD1306_WHITE);
  display.setCursor(0, 0);
  display.print("TEM:" + temperature_str);
  display.setCursor(0, 16);
  display.print("HUM:" + humidity_str);
  display.setCursor(0, 32);
  display.print("PRE:" + pressure_str);
  display.setCursor(0, 48);
  display.print("ALT:" + altitude_str);
  display.setTextSize(1);
  display.setTextColor(SSD1306_WHITE);
  display.setCursor(110, 4);
  display.print("*C");
  display.setCursor(110, 20);
  display.print("%");
  display.setCursor(110, 36);
  display.print("hPa");
  display.setCursor(110, 52);
  display.print("m");
  display.display();
}

// Function to display receiver outputs
void display_output()
{
  display.clearDisplay();
  display.setTextSize(1);
  display.setTextColor(SSD1306_WHITE);
  for (uint8_t index = 0; index < NUMBER_PWM; index++)
  {
    display.setCursor(0, index * 8);
    display.print("PWM" + String(index) + ":" + String(PWM_OUT[index]));
  }
  for (uint8_t index = 0; index < NUMBER_PWM; index++)
  {
    display.setCursor(50, index * 8);
    display.print("D" + String(index) + ":" + String(DOUT_OUT[index]));
  }
  for (uint8_t index = 0; index < NUMBER_PPM; index++)
  {
    display.setCursor(80, index * 8);
    display.print("PPM" + String(index) + ":" + String(PPM_OUT[index]));
  }
  display.display();
}

// Function to display the distance between reference position and new position
void display_gps()
{
  display.clearDisplay();
  display.setTextSize(1);
  display.setTextColor(SSD1306_WHITE);
  display.setCursor(0, 0);
  display.print("DISTANCE(m):");
  display.setTextSize(2);
  display.setTextColor(SSD1306_WHITE);
  display.setCursor(0, 8);
  display.print(distance);
  display.setTextSize(1);
  display.setTextColor(SSD1306_WHITE);
  display.setCursor(0, 40);
  display.print("REFERENCE:");
  display.setCursor(0, 48);
  display.print("LAT:" + String(reference_lat,2));
  display.setCursor(0, 56);
  display.print("LNG:" + String(reference_lng,2));
  display.display();
  display.setCursor(64, 40);
  display.print("POSITION:");
  display.setCursor(64, 48);
  display.print("LAT:" + String(new_lat,2));
  display.setCursor(64, 56);
  display.print("LNG:" + String(new_lng,2));
  display.display();
}

// ********************** Project Configuration ***************
void setup()
{

  // Initializes serial communication if macro is enabled
#if defined(DEBUG_ANALOG) || defined(DEBUG_DIGITAL) || defined(DEBUG_ENCODER) || defined(DEBUG_BUTTONS) || defined(DEBUG_AMBIENT) || defined(DEBUG_GPS) || defined(DEBUG_BATTERY)
  Serial.begin(115200);
#endif
  Serial1.begin(9600);

  // Initializes and configures the PWM pins
  for (uint8_t index = 0; index < NUMBER_PWM; index++)
  {
    pinMode(PWM_PINS[index], OUTPUT);
    analogWrite(PWM_PINS[index], PWM_OUT[index]);
  };

  // Initializes and configures the PPM pins
  for (uint8_t index = 0; index < NUMBER_PPM; index++)
  {
    SERVOS[index].attach(PPM_PINS[index]);
    SERVOS[index].write(PPM_OUT[index]);
  }

  // Initializes and configures the PWM pins
  for (uint8_t index = 0; index < NUMBER_DOUTS; index++)
  {
    pinMode(DOUT_PINS[index], OUTPUT);
    digitalWrite(DOUT_PINS[index], DOUT_OUT[index]);
  }

  // Initializes the LEDs
  for (uint8_t index = 0; index < NUMBER_LEDS; index++)
  {
    pinMode(LED_PINS[index], OUTPUT);
    digitalWrite(LED_PINS[index], LOW);
  }

  // Digital pins configuration
  for (uint8_t index = 0; index < NUMBER_BUTTONS; index++)
  {
    BUTTONS[index].attach(PINS_BUTTONS[index], INPUT);
    BUTTONS[index].interval(DEBOUNCE_INTERVAL);
  }

  // Configures Teensy ADC0
	adc->adc0->setReference(ADC_REFERENCE::REF_3V3);
	adc->adc0->setAveraging(32);
	adc->adc0->setResolution(12);
	adc->adc0->setConversionSpeed(ADC_CONVERSION_SPEED::VERY_HIGH_SPEED);
	adc->adc0->setSamplingSpeed(ADC_SAMPLING_SPEED::VERY_HIGH_SPEED);

  // Battery Voltage Pin Configuration
	pinMode(BATTERY_PIN, INPUT_DISABLE);

  // Initializes and configures the display
  display.begin(SSD1306_SWITCHCAPVCC, DISPLAY_ADDRESS);
  display.clearDisplay();
  display.display();

  // Initializes the ambient sensor
  ambient.begin();
  ambient.setTemperatureOversampling(BME680_OS_8X);
  ambient.setHumidityOversampling(BME680_OS_2X);
  ambient.setPressureOversampling(BME680_OS_4X);
  ambient.setIIRFilterSize(BME680_FILTER_SIZE_3);
  ambient.setGasHeater(320, 150);

  // Initializes and configures the radio
  radio.begin();
  radio.setChannel(radio_CHANNEL);
  radio.setDataRate(RF24_250KBPS);
  radio.setPALevel(RF24_PA_MIN);
  radio.setPayloadSize(sizeof(controller));
  radio.openWritingPipe(radio_ADDRESSES[radio_NUMBER]);
  radio.openReadingPipe(1, radio_ADDRESSES[!radio_NUMBER]);
  radio.startListening();
}

// ********************** Project Main Loop ***************
void loop()
{

  // ---------------------- Analog Readings --------------------
	// Reads Controller Battery Voltage
	if ((millis() - last_battery) > BATTERY_READING)
	{
		VD_VOUT = (adc->adc0->analogRead(BATTERY_PIN) * 3.3) / 4095.0;
		VD_VIN = (VD_VOUT / (VD_R2 / (VD_R1 + VD_R2))) - 0.12;
		if ((VD_VIN > last_VD_VIN + HYSTERESIS) || (VD_VIN < last_VD_VIN - HYSTERESIS))
		{
			analogWrite(LED_PINS[1], map(VD_VIN, MIN_VIN, 7.3, 0, 255));
			last_VD_VIN = VD_VIN;
		}
		last_battery = millis();
	}

#ifdef DEBUG_BATTERY
		Serial.print(VD_VIN);
		Serial.print(" | ");
		Serial.print(last_VD_VIN);
		Serial.println("");
#endif

  // Reads Receiver Buttons
  for (uint8_t index = 0; index < NUMBER_BUTTONS; index++)
  {
    BUTTONS[index].update();
    // buttons_readings[index] = BUTTONS[index].read();
    if (BUTTONS[index].read() != last_buttons_readings[index])
    {
      last_buttons_readings[index] = BUTTONS[index].read();
      if (BUTTONS[index].read() == LOW)
      {
        buttons_readings[index] = !buttons_readings[index];
        display.clearDisplay();
        display.display();
      }
    }
#ifdef DEBUG_BUTTONS
    Serial.print(buttons_readings[index]);
    Serial.print(" | ");
#endif
  }
#ifdef DEBUG_BUTTONS
  Serial.println("");
#endif

  if (radio.available(&channel))
  {
    bytes = radio.getPayloadSize();
    radio.read(&controller, bytes);
    digitalWrite(LED_PINS[0], HIGH);
#ifdef DEBUG_ANALOG
    for (uint8_t index = 0; index < 8; index++)
    {
      Serial.print(controller.analogs_message[index]);
      Serial.print(" | ");
    }
    Serial.println("");
#endif
#ifdef DEBUG_DIGITAL
    for (uint8_t index = 0; index < 8; index++)
    {
      Serial.print(controller.buttons_message[index]);
      Serial.print(" | ");
    }
    Serial.println("");
#endif
#ifdef DEBUG_ENCODER
    for (uint8_t index = 0; index < 2; index++)
    {
      Serial.print(controller.encoders_messsage[index]);
      Serial.print(" | ");
    }
    Serial.println("");
#endif
    last_message = millis();
  }
  else if ((millis() - last_message) > RX_TIMEOUT)
  {
    digitalWrite(LED_PINS[0], LOW);
    for (uint8_t index = 0; index < NUMBER_PWM; index++)
    {
      analogWrite(PWM_PINS[index], 0);
    }
    for (uint8_t index = 0; index < NUMBER_PPM; index++)
    {
      SERVOS[index].write(90);
    }
    for (uint8_t index = 0; index < NUMBER_DOUTS; index++)
    {
      digitalWrite(DOUT_PINS[index], 0);
    }
  }

  if (buttons_readings[0])
  {
    if (update_reference)
    {
      while (Serial1.available() > 0)
      {
        gps.encode(Serial1.read());
        reference_lng = gps.location.lng();
        reference_lat = gps.location.lat();
#ifdef DEBUG_GPS
        Serial.print("Ref. Latitude= ");
        Serial.print(reference_lat, 6);
        Serial.print("| Ref. Longitude= ");
        Serial.println(reference_lng, 6);
#endif
        update_reference = false;
      }
    }
    else
    {
      while (Serial1.available() > 0)
      {
        gps.encode(Serial1.read());
        if (gps.location.isUpdated())
        {
          new_lng = gps.location.lng();
          new_lat = gps.location.lat();
          distance = gps.distanceBetween(reference_lat, reference_lng, new_lat, new_lng);
#ifdef DEBUG_GPS
          Serial.print("Ref. Latitude= ");
          Serial.print(reference_lat, 6);
          Serial.print(" | Ref. Longitude= ");
          Serial.print(reference_lng, 6);
          Serial.print(" | New Latitude= ");
          Serial.print(reference_lat, 6);
          Serial.print(" | New Longitude= ");
          Serial.print(reference_lng, 6);
          Serial.print(" | Distance= ");
          Serial.print(distance, 6);
#endif
        }
      }
    }
    if ((millis() - gps_time) > GPS_INTERVAL)
    {
      display_gps();
      gps_time = millis();
    }
  }
  else if (buttons_readings[1])
  {
    if ((millis() - display_time) > UPDATE_INTERVAL)
    {
      display_controller();
      display_time = millis();
    }
  }
  else if (buttons_readings[2])
  {
    if ((millis() - ambient_time) > READING_INTERVAL)
    {

      // Reads ambient sensor
      ambient.performReading();
      temperature_reading = ambient.temperature;
      humidity_reading = ambient.humidity;
      pressure_reading = ambient.pressure / 100.00;
      air_quality_reading = ambient.gas_resistance / 1000.00;
      altitude_reading = ambient.readAltitude(sea_level_pressure);
      temperature_str = String(temperature_reading, 1);
      humidity_str = String(humidity_reading, 1);
      pressure_str = String(pressure_reading, 1);
      altitude_str = String(altitude_reading, 1);

#ifdef DEBUG_AMBIENT
      Serial.print("Temperature = ");
      Serial.print(temperature_reading);
      Serial.println(" *C");
      Serial.print("Pressure = ");
      Serial.print(pressure_reading);
      Serial.println(" hPa");
      Serial.print("Humidity = ");
      Serial.print(humidity_reading);
      Serial.println(" %");
      Serial.print("Air Quality = ");
      Serial.print(air_quality_reading);
      Serial.println(" KOhms");
      Serial.print("Altitude = ");
      Serial.print(altitude_reading);
      Serial.println(" m");
      Serial.println();
#endif

      // Updates timing
      ambient_time = millis();
      display_ambient();
    }
  }
  else if (buttons_readings[3])
  {
    for (uint8_t index = 0; index < NUMBER_PWM; index++)
    {
      PWM_OUT[index] = map(controller.analogs_message[index], 0, 4095, 0, 254);
      analogWrite(PWM_PINS[index], PWM_OUT[index]);
    }
    for (uint8_t index = 0; index < NUMBER_PPM; index++)
    {
      PPM_OUT[index] = map(controller.encoders_messsage[index], -180, 180, 0, 180);
      SERVOS[index].write(PPM_OUT[index]);
    }
    for (uint8_t index = 0; index < NUMBER_DOUTS; index++)
    {
      DOUT_OUT[index] = !controller.buttons_message[index];
      digitalWrite(DOUT_PINS[index], DOUT_OUT[index]);
    }
    display_output();
  }
  else if (!buttons_readings[0])
  {
    update_reference = true;
  }
  else if (!buttons_readings[3])
  {
    for (uint8_t index = 0; index < NUMBER_PWM; index++)
    {
      analogWrite(PWM_PINS[index], 0);
    }
    for (uint8_t index = 0; index < NUMBER_PPM; index++)
    {
      SERVOS[index].write(90);
    }
    for (uint8_t index = 0; index < NUMBER_DOUTS; index++)
    {
      digitalWrite(DOUT_PINS[index], 0);
    }
  }
}
// ************************************************************

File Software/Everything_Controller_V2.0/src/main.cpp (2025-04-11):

/**************************************************************
 * Everything Controller (v2.0)
 *
 * Base code for the "Everything Controller V2.0" to send data to a receiver.
 * Communication is based on RF24 using the NRF24L01+ module. The controller
 * sends data from 8 digital buttons, 2 joysticks (2 X-axis and 2 Y-axis),
 * two sliders, two rotary potentiometers and two rotary encoders.
 * With this data, it is possible to control anything.
 *
 * Written by Giovanni de Castro (10/03/2024).
 *************************************************************/

// ********************** Project Libraries *******************
// Arduino framework
#include <Arduino.h>

// NRF24L01 control libraries
#include <SPI.h>
#include <RF24.h>

// SSD1327 control libraries
#include <Adafruit_GFX.h>
#include <Adafruit_SSD1327.h>
#include "icons.h"

// Teensy ADC libraries
#include <ADC.h>
#include <ADC_util.h>

// Moving average library
#include <movingAvg.h>

// Encoder library
#include <Encoder.h>

// Button library
#include <Bounce2.h>

// ********************** Project Macros **********************
// Macro to disable or enable serial debugging
// #define DEBUG_BATTERY
// #define DEBUG_ANALOG
// #define DEBUG_DIGITAL
// #define DEBUG_ENCODER
// #define DEBUG_GENERIC // used to debug logic without the controller readings

// Controller pins definitions (Analog Inputs)
#define PIN_JXAL A6	 // Joystick X Axis Left
#define PIN_JYAL A7	 // Joystick Y Axis Left
#define PIN_JXAR A9	 // Joystick X Axis Right
#define PIN_JYAR A8	 // Joystick Y Axis Right
#define PIN_RPOTL A3 // Rotary Potentiometer Left
#define PIN_SPOTL A2 // Slider Potentiometer Left
#define PIN_RPOTR A1 // Rotary Potentiometer Right
#define PIN_SPOTR A0 // Slider Potentiometer Right

// Controller pins definitions (Digital Inputs)
#define PIN_JBTL 0	  // Joystick Button Left
#define PIN_JBTR 1	  // Joystick Button Right
#define PIN_EBTL 2	  // Encoder Button Left
#define PIN_EBTR 3	  // Encoder Button Right
#define PIN_ECLKL 4	  // Encoder CLK Left
#define PIN_EDTL 5	  // Encoder DT Left
#define PIN_EDTR 6	  // Encoder DT Right
#define PIN_ECLKR 7	  // Encoder CLK Right
#define PIN_MXBTEL 24 // Cherry MX Button Left
#define PIN_MXBTCL 33 // Cherry MX Button Center Left
#define PIN_MXBTER 31 // Cherry MX Button Right
#define PIN_MXBTCR 26 // Cherry MX Button Center Right
#define PIN_DIPER 29  // DIP Switch 1
#define PIN_DIPCR 30  // DIP Switch 2
#define PIN_DIPCL 28  // DIP Switch 3
#define PIN_DIPEL 27  // DIP Switch 4

// Controller pins definitions (LEDs Outputs)
#define PIN_LED1 25 // RF Message Feedback LED
#define PIN_LED2 32 // Battery Level Feedback LED | Vibracall Motor

// NRF24L01 pins definitions
#define PIN_CE 9
#define PIN_CSN 10

// SSD1327 display Display definitions
#define DISPLAY_WIDTH 128
#define DISPLAY_HEIGHT 128
#define DISPLAY_ADDRESS 0x3D
#define DISPLYA_RESET -1

// ********************** Project Objects *********************
// Controller encoder objects
const uint8_t NUMBER_KNOBS = 2;
Encoder KNBOS[NUMBER_KNOBS] = {
	Encoder(PIN_ECLKL, PIN_EDTL),
	Encoder(PIN_ECLKR, PIN_EDTR)};

// Controller buttons objects
const uint8_t NUMBER_BUTTONS = 8;
const uint8_t DEBOUNCE_INTERVAL = 50;
Bounce BUTTONS[NUMBER_BUTTONS];
const uint8_t PINS_BUTTONS[NUMBER_BUTTONS] = {PIN_JBTL, PIN_JBTR, PIN_EBTL, PIN_EBTR, PIN_MXBTEL, PIN_MXBTCL, PIN_MXBTCR, PIN_MXBTER};
bool buttons_readings[NUMBER_BUTTONS];
bool MXbuttons_states[NUMBER_BUTTONS / 2] = {false, false, false, false};

// MX SW Latch Switches Pins
const uint8_t DIP_PINS[NUMBER_BUTTONS / 2] = {PIN_DIPEL, PIN_DIPCL, PIN_DIPCR, PIN_DIPER};
bool MX_latch[NUMBER_BUTTONS / 2];
bool latch_change[NUMBER_BUTTONS / 2] = {true, true, true, true};

// Analog Pins
const uint8_t NUMBER_ANALOG_INS = 8;
const uint8_t ANALOG_PINS[NUMBER_ANALOG_INS] = {PIN_JXAL, PIN_JYAL, PIN_JXAR, PIN_JYAR, PIN_RPOTL, PIN_RPOTR, PIN_SPOTL, PIN_SPOTR};
uint16_t analog_readings[NUMBER_ANALOG_INS];
uint16_t averages_readings[NUMBER_ANALOG_INS];
const uint8_t NUMBER_SAMPLES = 10;
movingAvg analog_averages[NUMBER_ANALOG_INS] = {
	movingAvg(NUMBER_SAMPLES),
	movingAvg(NUMBER_SAMPLES),
	movingAvg(NUMBER_SAMPLES),
	movingAvg(NUMBER_SAMPLES),
	movingAvg(NUMBER_SAMPLES),
	movingAvg(NUMBER_SAMPLES),
	movingAvg(NUMBER_SAMPLES),
	movingAvg(NUMBER_SAMPLES)};

// LEDs Pins
const uint8_t NUMBER_LEDS = 2;
const uint8_t LED_PINS[NUMBER_LEDS] = {PIN_LED1, PIN_LED2};

// NRF24L01 control object
RF24 radio(PIN_CE, PIN_CSN);

// SSD1327 display control object
Adafruit_SSD1327 display(DISPLAY_WIDTH, DISPLAY_HEIGHT, &Wire, DISPLYA_RESET, 3400000);

// Teensy analog pins object
ADC *adc = new ADC();

// ********************** Project Variables *******************
// Radio address and channel
const uint8_t radio_CHANNEL = 71;
const uint8_t radio_ADDRESSES[2][6] = {{0xB6, 0xE9, 0x00, 0x7A, 0x43}, {0x10, 0xCA, 0x87, 0x3F, 0xD8}};
const bool radio_NUMBER = 0;

// Variables for failsafe and display update
bool message_acknowledged;
bool last_acknowledgement;
bool vibration_animation = true;
uint8_t vibration_PWM = 250;
bool signal_state = false;

// Encoders reading variables
int16_t new_positions[NUMBER_KNOBS] = {0, 0};
int16_t last_positions[NUMBER_KNOBS] = {0, 0};

// Variables for radio timings
unsigned long last_message = 0;
const uint8_t TX_INTERVAL = 10; // [ms] | 1 ms to acknowlegement (6 ms total)
unsigned long last_message_sent = 0;
const uint16_t TX_TIMEOUT = 2500; // [ms] | FAILSAFE

// Battery Voltage Divider Variables
const uint8_t BATTERY_PIN = A14;
const uint8_t NUMBER_VREADS = 50;
float VD_VOUT = 0.0;
float VD_VIN = 0.0;
float last_VD_VIN = 0.0;
const float VD_R1 = 51000.0;
const float VD_R2 = 33000.0;
const float MIN_VIN = 6.5;
const float HYSTERESIS = 0.1;
unsigned long last_battery = 5000;
const uint16_t BATTERY_READING = 5000; // [ms]
uint8_t battery_icon = 4;
uint8_t last_battery_icon = 0;
uint16_t average_battery = 0;
movingAvg battery_readings(NUMBER_VREADS);

// Boolean to update OLED Display
bool update_display = true;

// Controller variables structure
typedef struct
{
	bool buttons_message[8];
	uint16_t analogs_message[8];
	int16_t encoders_messsage[2];
} controller_variables;
controller_variables controller;
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

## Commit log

2024-08-08 Ideal_Reaceiver
    Inclusion of the Ideal Receiver project.
    [Everything_Controller_Handle.FCStd, Everything_Controller_Ideal_Receiver.kicad_pcb, Everything_Controller_Ideal_Receiver.kicad_sch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]
2024-11-15 Better_Logic
    Better logic for controller and ideal receiver for better performance.
    [Everything_Controller_Backplate-Body.dxf, Everything_Controller_Backplate-Body.stl, Everything_Controller_Backplate.FCStd]
